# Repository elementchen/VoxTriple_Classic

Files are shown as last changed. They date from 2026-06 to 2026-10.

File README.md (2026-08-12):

# VoxTriple — ESP32 Bluetooth HID Keyboard & HFP Microphone System<br/>ESP32 蓝牙 HID 键盘与 HFP 麦克风系统





> An ESP32-based multi-mode Bluetooth system providing a classic Bluetooth HID Keyboard and an HFP Hands-Free Client (Microphone) simultaneously. Includes programmable key mapping, wired ultra-fast OTA updating, and modern native companion apps for Windows and macOS.
>
> 基于 ESP32 的多模蓝牙系统。同时拉起经典蓝牙 HID 键盘与 HFP 免提客户端（麦克风）双重角色。支持自定义按键映射配置、20秒极速有线 OTA 升级机制，并配套提供适用于 Windows 和 macOS 的现代原生配置客户端。

----

## 🚀 Quick Start / 极速新手指南

为了让不懂代码、不熟悉开发环境的小白用户以最傻瓜式的方式运行本项目，我们提供以下极速上手指引。请根据您的设备状态选择对应操作：

### 1. 首次拿到开发板？（首次物理初始化）
如果您是**全新开发板**，或者**刷过别的程序的板子**，请先进行一次物理初始化烧录：
* **第一步**：下载乐鑫官方的 [ESP32 Flash Download Tool 官方烧录工具](https://docs.espressif.com/projects/esp-test-tools/zh_CN/latest/esp32/production_stage/tools/flash_download_tool.html)；
* **第二步**：从项目 [GitHub Releases](https://github.com/elementchen/VoxTriple_Classic/releases) 页面，下载最新版本的**「一键合并固件」**（文件名为 **`esp32_bt_mic_merged_vX.X.X.bin`**）；
* **第三步**：打开烧录工具，导入该 `.bin` 文件，**烧录首偏置地址填 `0x0`**，点击 **`START`** 即可一键刷入。刷入后复位板子，您的系统即已成功运行！
> 💡 详细的傻瓜图文操作步骤，请点击阅读：[📖 中文新手固件烧录与更新教程](docs/flash_guide_zh.md)

### 2. 以后需要升级版本？（日常一键免代码 OTA）
一旦您的板子成功跑起来了，如果日后官方发布了新版，您**完全不需要**使用复杂的官方烧录工具。直接运行配置客户端即可一键闪电更新：
* **第一步**：双击运行免依赖的 Windows 配置程序 **`VoxTripleConfig.exe`** 并在最上面连接您的串口；
* **第二步**：连接成功后，App 会在后台自动比对版本。一旦云端有更新，顶端版本号旁会**自动浮现高亮的「Update / 升级固件」按钮**；
* **第三步**：点击按钮，App 将全自动切换页签、全自动从 GitHub 后台为您分包下载**「常规应用固件」**（文件名为 **`esp32_bt_mic_vX.X.X.bin`**，无需您手工下载），并在 **20秒** 内通过物理串口闪电完成 OTA 直写升级并自动软重启！

----

## Features / 功能特性

- **Dual-Profile Bluetooth** — Act as a Bluetooth HID Keyboard and an HFP Hands-Free Client simultaneously. Windows and macOS recognize it natively as a keyboard and an audio input device. No drivers needed.
  
  **经典蓝牙多协议共存** — 同时扮演经典蓝牙 HID 键盘与 HFP 免提客户端（麦克风）双重 Profile（即多协议复合设备）。系统原生免驱识别为音频输入设备与实体键盘。

- **Teal Visual & Dotted Focus-Free UI** — Sleek card-layout desktop companion applications designed in native Python Tkinter. 100% free of dotted focus rings and fully integrated with OS style behaviors.
  
  **卡片式无虚线原生 UI** — 基于 Python Tkinter 匠心设计的卡片式配置客户端，彻底铲除点击时难看的焦点虚线框，完美融合系统原生外观（提供直观的蓝色勾选框 ☒ 交互）。

- **Smart Online & 20s Wired OTA** — Dynamically compares the local firmware version with the latest release on GitHub. Features one-click auto-downloading with progress meters and automatic fallback to a local `cache/` directory for offline updating. Complete flash transfer finishes lossless in 20-30 seconds.
  
  **智能在线与20秒有线 OTA** — 自动与 GitHub 云端比对版本。支持一键全自动后台下载（带百分比进度），且支持检测本地 `cache/` 目录进行离线升级。固件端 100% 物理绕过 VFS 控制字符拦截，20秒闪电完成写入并自动复位。

- **Version-Stamped Releases** — Build system automatically extracts the firmware version during build time and duplicates a version-stamped binary (e.g., `esp32_bt_mic_v1.0.3.bin`) to prevent compiler overwrites.
  
  **版本自动命名** — 编译时自动从代码中提取当前版本号，在 `build/` 目录下复制出一份带有版本戳的固件（如 `esp32_bt_mic_v1.0.3.bin`），防止重复编译覆盖，方便 GitHub Releases 归档。

- **Cross-Platform Config Apps** — 
  - **Windows App**: Communication via physical USB Serial (COM), featuring live physical key press monitor with highlight colors.
  - **macOS App**: Connection via physical USB Serial, using Apple Accessibility features to capture keystrokes locally.
  
  **跨平台配置客户端** —
  - **Windows 客户端**: 通过物理 USB 串口（COM 端口）有线通信，内置大字号物理按键按下事件监控器。
  - **macOS 客户端**: 通过物理 USB 串口有线通信，联动 macOS 系统辅助功能进行按键捕获。

- **mSBC Wideband Speech** — 16 kHz wideband speech pipeline with DSP audio processing (moving average + high-pass filtering). Realizes telephone-grade crisp speech input.
  
  **mSBC 宽带语音** — 16kHz 采样率的高清录音通道，内置 DSP 算法（滑动平均降噪 + 高通滤波滤除低频杂音）。提供高清晰度的语音输入。

---

## Hardware / 硬件清单

| Component 组件 | Model 型号 | Qty 数量 |
|---|---|---|
| Dev Board 开发板 | WEMOS ESP32 (18650 Battery Holder) | 1 |
| Microphone 麦克风 | INMP441 MEMS I2S module | 1 |
| Buttons 按钮 | 6×6mm tactile switch / 轻触开关 | 4 |

---

## Wiring / 接线说明

```
INMP441 (麦克风) → ESP32:
  VDD  → 3.3V          Never connect to 5V! / 严禁接 5V！
  GND  → GND
  L/R  → GND           Left channel / 必须接地设为左声道
  SD   → GPIO 17       I2S Serial Data (SD)
  WS   → GPIO 22       Word Select (LRC / WS)
  SCK  → GPIO 21       Serial Clock (BCLK / SCK)

Buttons (按键) → ESP32:
  Button 1 → GPIO 4     PTT语音 / 深度睡眠唤醒键 (Default: Enter / 回车)
  Button 2 → GPIO 18    Key 2 (Default: Esc / 退出)
  Button 3 → GPIO 19    Key 3 (Default: Space / 空格)
  Button 4 → GPIO 23    Key 4 (Default: Tab / 制表键) [长按 3 秒擦除蓝牙绑定并重启]

Onboard LED (板载蓝色贴片指示灯) → ESP32:
  - 物理固化在 GPIO 16 上，无需任何外部接线与电阻！
  - 低电平有效 (Active Low)，由代码自动控制，在 Button 1 按下说话时亮起指示，松开时熄灭。

* All buttons are active-low (GPIO → Button → GND) with internal pull-up enabled.
* 所有按键均为低电平有效，接线方式为 GPIO 引脚接按键再到 GND，使用内部上拉。
```

---

## Setup & Flash Guide / 固件编译烧录

> [!TIP]
> **如果您是普通用户（不懂代码、未安装 Python 及 ESP-IDF 开发环境）**，请直接跳转阅读我们专门为您准备的：
> 👉 **[新手固件烧录与更新指南 (docs/flash_guide_zh.md)](docs/flash_guide_zh.md)**。
>
> If you are a general user (not familiar with coding, terminal commands or ESP-IDF build tools), please read our beginner-friendly tutorial:
> 👉 **[Firmware Flashing Guide (For Beginners)](docs/flash_guide_zh.md)**.

### 1. Initialize ESP-IDF Environment
Ensure you have ESP-IDF v5.5.1 installed. Start your terminal (e.g. PowerShell) and run:
确保您已安装 ESP-IDF v5.5.1。启动终端，执行：

```powershell
$env:IDF_PATH="C:\Espressif\frameworks\esp-idf-v5.5.1"
. C:\Espressif\Initialize-Idf.ps1
```

### 2. Build & Flash
Navigate to the `esp32_bt_mic` workspace. Build and flash target hardware at a highly stable **115200** baud rate to isolate potential channel line noise:
切换至 `esp32_bt_mic` 文件夹。为了彻底隔离阻抗线路噪声，建议使用 **115200** 稳定波特率进行烧写：

```powershell
cd esp32_bt_mic
# Build project
idf.py build

# Flash at 115200 baud
idf.py -p COM5 -b 115200 flash
```

---

## Configuration Apps Guide / 配置客户端使用说明

### 1. Windows Companion App (USB 物理串口有线连接)
Located under `windows_app_python/`. Runs natively on Python 3.
位于 `windows_app_python/` 目录下，基于 Python 3。

#### Requirements & Setup
```powershell
cd windows_app_python
pip install -r requirements.txt
python vox_triple.py
```

#### standalone EXE compilation
We support compiling the app into a single standalone, DLL-free `.exe` file. Install `PyInstaller` and compile:
本客户端支持一键打包为独立的免依赖 `.exe` 应用程序。执行以下指令完成编译：

```powershell
pip install pyinstaller
pyinstaller --noconfirm --onefile --windowed --name="VoxTripleConfig" vox_triple.py
# Output path / 输出目录: windows_app_python/dist/VoxTripleConfig.exe
```

#### App Tabs Details
- **Keyboard Config (键盘配置)**: Key mapping, TX power levels, and sleep toggles. Apply configuration wirelessly or via USB instantly (Hot Update).
- **Firmware OTA (固件升级)**: Dynamic updates with automatic GitHub checks. Prompts a smart upgrade button near the version tag, downloads latest bin into a local `cache/` directory, and flashes the device in 20s.
- **Info (说明书)**: Built-in help and user manual.

---

### 2. macOS Companion App (USB 物理串口有线连接)
Located under `MAC_app_python/`. Connects to the board over USB serial, sharing the identical key configurations, dynamic updates, and 20-second OTA flash capabilities with the Windows version.
位于 `MAC_app_python/` 目录下。直接通过 USB 串口线连接设备，共享与 Windows 端 100% 对齐的改键配置、云版本比对、以及极速 OTA 烧录体验。

#### Setup
```bash
cd MAC_app_python
pip install -r requirements.txt
python3 vox_triple_mac.py
```

> [!IMPORTANT]
> macOS keypress hook requires **Accessibility Permission** in macOS system settings:
>
> macOS 下键盘按键捕获需要您开启**系统辅助功能权限**：
> `系统设置` → `隐私与安全性` → `辅助功能`，添加终端或此程序并允许。

---

## Project Directory Structure / 项目结构

```
VoxTriple/
├── esp32_bt_mic/                  # ESP32 firmware / ESP32 固件 (ESP-IDF 5.5)
│   ├── CMakeLists.txt
│   ├── partitions.csv             # Custom partition table (OTA_0, OTA_1, NVS)
│   ├── sdkconfig.defaults         # Config defaults for Dual-profile BT (HID & HFP)
│   └── src/
│       ├── main.c                 # Entry / 初始化入口
│       ├── bt_init.c              # Bluetooth stack & Controller configurations
│       ├── bt_hfp_hf.c            # HFP Client & SCO wideband speech logic
│       ├── classic_hidd.c         # Classic Bluetooth HID Keyboard descriptors & events
│       ├── spp_server.c           # (Legacy) Bluetooth Classic SPP command channel
│       ├── uart_console.c         # Wired hardware Console UART driver & 20s OTA engine
│       ├── config_cmd.c           # Common configuration parser (cJSON-based)
│       ├── audio_capture.c        # I2S legacy microphone driver for INMP441
│       └── config_storage.c       # Non-volatile storage (NVS) read/write
│
├── windows_app_python/            # Windows config App / Windows 客户端 (USB 串口)
│   ├── vox_triple.py              # Main GUI script / 界面主入口
│   ├── spp_client.py              # Asynchronous Serial packet stream controller
│   ├── config_service.py          # Persistence storage service
│   ├── keyboard_io.py             # Win32 key hooks and display formatter
│   └── requirements.txt
│
└── MAC_app_python/                # macOS config App / macOS 客户端 (USB 串口)
    ├── vox_triple_mac.py          # Main GUI script
    ├── keyboard_io_mac.py         # macOS accessibility key capture hook
    └── requirements.txt
```

---

## License / 许可证
MIT License © 2024-2026

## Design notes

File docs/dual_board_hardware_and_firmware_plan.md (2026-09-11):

# VoxTriple 双开发板兼容与硬件适配方案规划书
> **文档版本**：v1.0  
> **适用硬件**：  
> 1. WEMOS ESP32 Board with 18650 Battery Holder（经典版 / 18650款）  
> 2. ESP32 Lite V1.0.0（LOLIN32 Lite 兼容款 / 轻量版）  
> **状态**：方案规划与技术论证（暂未修改代码，待用户确认）

---

## 1. 背景与目标

为了满足产品后续系列化、轻量化与结构微型化的需求，项目计划引入 **ESP32 Lite V1.0.0** 开发板。由于两款开发板在尺寸、引脚分布及板载硬件外设上存在物理差异，本项目提出一套**“同一套固件自适应双板、上位机智能识别并激活对应引脚配置”**的完整软硬件解决方案。

### 核心设计原则
1. **按键引脚零破坏性兼容**：两款开发板的 4 个物理按键使用**完全相同**的 GPIO 引脚，避免按键逻辑和用户使用习惯的分化。
2. **麦克风与 LED 引脚精准适配**：针对 ESP32 Lite V1 缺少 GPIO 21 以及板载 LED 变动的情况，提供最优接线，并在底层通过板级抽象层（Board Profile）动态加载。
3. **上位机可视化识别**：客户端（Windows / macOS）连接设备后能自动识别开发板型号，展示对应板卡铭牌，并支持用户切换写入生效。
4. **单固件全生命周期维护**：云端 OTA 与本地烧录无需维护两套 bin，固件根据内部 NVS 存储的硬件型号自适应初始化硬件。

---

## 2. 硬件引脚特性与差异深度对比

基于对原板原理图及仓库内 `docs/lolin32.pdf`（ESP32 Lite / LOLIN32_Lite V1.0.0 原厂原理图）的交叉比对，两款板卡的关键差异如下：

| 关键要素 | WEMOS 18650 电池版（原板） | ESP32 Lite V1.0.0（新板） | 差异影响与设计对策 |
| :--- | :--- | :--- | :--- |
| **板载 LED** | **GPIO 16**（低电平点亮） | **GPIO 22**（低电平点亮） | 新板物理固化在 GPIO 22，固件需根据板型切换 LED 驱动引脚。 |
| **GPIO 21 引出情况** | **正常引出**（用作 I2S BCK） | **未引出！**（物理排针无 Pin 21） | **最大物理差异**。新板必须改用其他空闲数字 GPIO 作为 I2S 时钟。 |
| **GPIO 22 引出情况** | 正常引出（原用作 I2S WS） | 引出，但**已被板载 LED 占用** | 新板不能再用 GPIO 22 接麦克风 WS，否则 16kHz 时钟会干扰 LED。 |
| **GPIO 17 引出情况** | 正常引出（用作 I2S DATA） | 正常引出（右侧） | 两款板均有且均为空闲引脚。 |
| **GPIO 4 (RTC IO 10)** | 正常引出（Button 1，支持唤醒） | 正常引出（右侧） | 两款板均支持 RTC Deep Sleep 唤醒，引脚完全对齐。 |
| **GPIO 18 / 19 / 23** | 正常引出（Button 2 / 3 / 4） | 正常引出（右侧） | 两款板均支持，引脚完全对齐。 |
| **电池接口** | 板载 18650 电池座 | 板载 2.0mm JST 锂电插座 + TP4054 | 供电方式变轻巧，接口不同，核心供电逻辑一致。 |
| **输入专用引脚** | GPIO 34, 35, 36, 39 | GPIO 34, 35 | 仅限输入，无内部上下拉，不建议用作普通按键或输出。 |
| **启动引脚 (Strapping)**| GPIO 0, 2, 12, 15 | GPIO 0, 2, 12, 15 | GPIO 12 严禁接强上拉（否则 Flash 供电错误导致变砖），避开使用。 |

---

## 3. ESP32 Lite V1.0.0 推荐接线方案

结合引脚物理可用性、抗干扰要求以及不强制同一侧引脚的原则，针对 **ESP32 Lite V1.0.0** 制定如下推荐方案：

### 3.1 核心接线定义表（ESP32 Lite V1.0.0）

| 模块 / 外设 | 外设引脚 | ESP32 Lite V1 推荐引脚 | 排针方位 | 详细说明 |
| :--- | :--- | :--- | :--- | :--- |
| **INMP441** | **VDD** | **3V3** | 左侧排 Pin 2 | 必须接 3.3V，严禁接 5V |
| | **GND** | **GND** | 左侧排 Pin 4 | 共地 |
| | **L/R** | **GND** | 左侧排 Pin 4 | 接地选择左声道 |
| | **SD** (DATA) | **GPIO 25** | 左侧排 Pin 9 | I2S 串行数据输入 |
| | **WS** (LRCLK) | **GPIO 26** | 左侧排 Pin 10 | I2S 声道字选择（时钟） |
| | **SCK** (BCLK) | **GPIO 27** | 左侧排 Pin 11 | I2S 位时钟 |
| **按键 1** | 引脚一端 | **GPIO 4** | 右侧排 Pin 9 | 语音 PTT 键 / Deep Sleep 唤醒键（低电平有效） |
| | 引脚另一端 | **GND** | 右侧排 Pin 1 | 按键按下时接地，内部弱上拉 |
| **按键 2** | 引脚一端 | **GPIO 18** | 右侧排 Pin 5 | 快捷键 2（低电平有效） |
| | 引脚另一端 | **GND** | 右侧排 Pin 1 | 按键按下时接地，内部弱上拉 |
| **按键 3** | 引脚一端 | **GPIO 19** | 右侧排 Pin 3 | 快捷键 3（低电平有效） |
| | 引脚另一端 | **GND** | 右侧排 Pin 1 | 按键按下时接地，内部弱上拉 |
| **按键 4** | 引脚一端 | **GPIO 23** | 右侧排 Pin 4 | 快捷键 4（低电平有效） |
| | 引脚另一端 | **GND** | 右侧排 Pin 1 | 按键按下时接地，内部弱上拉 |
| **板载 LED** | 贴片 LED | **GPIO 22** | 板载内部物理固化 | **无需外接任何引线**，固件自动控制（低电平亮，高电平灭） |

---

### 3.2 接线方案设计优势分析

1. **按键 100% 保持统一**：
   * **Button 1 ~ 4 依然完全使用 GPIO 4, 18, 19, 23**。
   * 好处：两款板的按键硬件定义一模一样，按键扫描、消抖、Deep Sleep RTC 唤醒逻辑完全共享，代码零分叉。
2. **INMP441 左侧集中式布线（极为优雅）**：
   * 在 ESP32 Lite V1.0.0 的左侧排针上，`3V3`、`GND`、`GPIO 25`、`GPIO 26`、`GPIO 27` 是**完全连续相邻**的排针！
   * 麦克风的 5 根杜邦线可以做成一个一体化的 5-Pin 排插直接插在左侧，走线极短，完全不需要横跨板子飞线，极大地降低了高频 I2S 信号的高频串扰与杂音。
   * GPIO 25, 26, 27 是标准通用 GPIO，且不属于 Boot Strapping Pin，对系统启动无任何不良影响。
3. **LED 彻底解耦**：
   * 原板：LED 走 GPIO 16；
   * 新板：LED 走 GPIO 22。
   * 固件层只定义一个逻辑 LED 接口，硬件层根据型号动态映射输出。

---

## 4. 固件架构设计（单固件双板兼容）

为了避免产生 `firmware_wemos.bin` 与 `firmware_lite.bin` 导致维护分叉与 OTA 混乱，采用**“运行时板级参数抽象”**机制。

### 4.1 数据结构定义（Board Profile）
在固件中定义硬件型号枚举与引脚配置结构体：

```c
typedef enum {
    BOARD_MODEL_WEMOS_18650 = 0, // 经典 18650 版
    BOARD_MODEL_ESP32_LITE_V1 = 1, // ESP32 Lite V1.0.0 版
} board_model_t;

typedef struct {
    board_model_t model;
    const char *model_name;
    gpio_num_t led_gpio;
    gpio_num_t i2s_bck_gpio;
    gpio_num_t i2s_ws_gpio;
    gpio_num_t i2s_data_gpio;
    gpio_num_t btn_gpios[4]; // 均为 4, 18, 19, 23
} board_profile_t;
```

预设配置表：
```c
static const board_profile_t s_board_profiles[] = {
    [BOARD_MODEL_WEMOS_18650] = {
        .model = BOARD_MODEL_WEMOS_18650,
        .model_name = "WEMOS 18650",
        .led_gpio = GPIO_NUM_16,
        .i2s_bck_gpio = GPIO_NUM_21,
        .i2s_ws_gpio = GPIO_NUM_22,
        .i2s_data_gpio = GPIO_NUM_17,
        .btn_gpios = { GPIO_NUM_4, GPIO_NUM_18, GPIO_NUM_19, GPIO_NUM_23 }
    },
    [BOARD_MODEL_ESP32_LITE_V1] = {
        .model = BOARD_MODEL_ESP32_LITE_V1,
        .model_name = "ESP32 Lite V1",
        .led_gpio = GPIO_NUM_22,
        .i2s_bck_gpio = GPIO_NUM_27,
        .i2s_ws_gpio = GPIO_NUM_26,
        .i2s_data_gpio = GPIO_NUM_25,
        .btn_gpios = { GPIO_NUM_4, GPIO_NUM_18, GPIO_NUM_19, GPIO_NUM_23 }
    }
};
```

### 4.2 NVS 持久化存储
* 在 NVS 的 `bt_config` 命名空间下新增 `hw_model` 键（`uint8_t`，默认为 `0`）。
* 设备上电初始化时：
  1. `config_storage_load_board_model(&model)` 读取配置；
  2. 若 NVS 为空，默认加载 `BOARD_MODEL_WEMOS_18650`（保证所有旧设备 OTA 后平滑过渡无感）；
  3. 系统将对应的 `led_gpio` 注册给 `button_handler`，将 `i2s_*_gpio` 注册给 `audio_capture`；
  4. 当收到客户端切换板型指令时，更新 NVS 并重启生效。

---

## 5. SPP 串口协议扩充设计

在现有的 SPP 二进制命令集（`uart_console.c`）基础上扩充 2 个指令：

### 5.1 命令定义

| 命令字 (CMD) | 名称 | 方向 | 数据长度 | 说明 |
| :--- | :--- | :--- | :--- | :--- |
| **0x0C** | `CMD_GET_BOARD_MODEL` | PC $\rightarrow$ 板 | 0 Byte | 请求当前板卡型号 |
| **0x0C** (ACK)| `CMD_GET_BOARD_MODEL_ACK` | 板 $\rightarrow$ PC | 2 Bytes | 返回：`[Status(0x00), ModelID(0/1)]` |
| **0x0D** | `CMD_SET_BOARD_MODEL` | PC $\rightarrow$ 板 | 1 Byte | 设置板卡型号：`[ModelID(0/1)]` |
| **0x0D** (ACK)| `CMD_SET_BOARD_MODEL_ACK` | 板 $\rightarrow$ PC | 1 Byte | 返回：`[Status(0x00)]`，设备随后自动重启 |

---

## 6. 上位机客户端（windows_app_python）交互与 UI 升级设计

现有的配置工具已升级为现代 WebView 架构。在此基础上进行如下无缝增强：

1. **自动读取并展示板卡铭牌**：
   * 客户端在点击 `CONNECT` 建立串口握手后，自动通过 `CMD_GET_BOARD_MODEL` 获取硬件版本。
   * 在状态栏与固件信息旁增加 **“硬件型号 (Hardware Model)”** 徽章：
     * 显示：`🟢 Wemos 18650 电池版` 或 `🟣 ESP32 Lite V1.0.0`。
2. **硬件型号切换与激活入口**：
   * 在配置界面底部或固件区增加“切换硬件型号”的下拉选择框。
   * 当用户需要将固件刷入新开发板，或者组装了 ESP32 Lite V1.0.0 时，可在此处选择 `ESP32 Lite V1.0.0`。
   * 点击 `Save & Switch / 保存并激活板型` 后，客户端下发 `CMD_SET_BOARD_MODEL`，开发板完成配置后自动重启，即刻激活新引脚映射。
3. **配置文件隔离机制（按板型保存配置）**：
   * 客户端本地保存按键预设时，以板型为维度进行预设关联（例如 `config_wemos_18650.json` 与 `config_esp32_lite.json`），用户在不同硬件间切换时，按键配置一键精准导入。

---

## 7. 开发路线与实施计划（Roadmap）

严格遵循“先论证、后开发、绝不破坏成熟功能”原则，分阶段推进：

- [x] **阶段一：硬件差异调研与引脚方案规划**（当前已完成，形成本文档）
- [ ] **阶段二：用户评审确认**
  * 确认接线方案（尤其是麦克风使用 GPIO 25, 26, 27 的便利性）；
  * 确认单固件自适应方案是否满足系列化生产需求。
- [ ] **阶段三：固件板级抽象层实现**
  * 编写 `board_profile.h` 与 `board_profile.c`；
  * 重构 `audio_capture.c` 与 `button_handler.c`，使用动态引脚变量取代宏定义；
  * `uart_console.c` 实现板型读写 SPP 指令。
- [ ] **阶段四：客户端识别与配置 UI 实现**
  * `spp_client.py` 封装 `read_board_model` 与 `write_board_model`；
  * `web/index.html` 与 `web/app.js` 增加开发板型号渲染和切换交互。
- [ ] **阶段五：双板实物联调与验证**
  * 测试 Wemos 18650 原有功能的回归（100% 兼容）；
  * 测试 ESP32 Lite V1.0.0 的麦克风录音音质、按键响应及 Deep Sleep 唤醒。

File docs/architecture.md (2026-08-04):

# ESP32 蓝牙麦克风键盘复合系统 - 系统架构 (v1.0.10)

## 概述

本项目实现了一个基于 ESP32 的经典蓝牙 HID 键盘与 HFP 麦克风复合系统，包含两个主要组件：
1. **ESP32 固件**：通过经典蓝牙实现实体 HID 键盘功能与 HFP 免提音频录音，并由代码驱动板载 LED 作反馈。
2. **有线配置客户端 (Win/Mac)**：通过 USB 物理串口与板子直接通信，实现按键自定义映射与极速 20s OTA 升级。

## 系统架构图

```
┌─────────────────────────────────────────────────────────┐
│                    Windows / macOS PC                   │
│  ┌──────────────┐  ┌──────────────┐  ┌──────────────┐  │
│  │ 蓝牙音频输入  │  │ 蓝牙虚拟键盘  │  │ 有线配置 App │  │
│  │ (HFP HF)     │  │ (HID Device) │  │ (USB Serial) │  │
│  └──────┬───────┘  └──────┬───────┘  └──────┬───────┘  │
│         │                 │                 │           │
│         └────────┬────────┴─────────────────┼───────────┼── (配对和改键通道)
│                  │ Classic BT               │ USB SPP   │
└──────────────────┼──────────────────────────┼───────────┘
                   │                          │
┌──────────────────┼──────────────────────────┼───────────┐
│                  │        ESP32             │           │
│  ┌───────────────┴──────────────────────────┴───────┐   │
│  │           Bluetooth Controller & Stack           │   │
│  │  ┌─────────────┐  ┌─────────────────────────┐    │   │
│  │  │   HFP HF    │  │    Classic HID Device   │    │   │
│  │  │  (SCO音频)  │  │      (键盘物理事件)     │    │   │
│  │  └──────┬──────┘  └───────────┬─────────────┘    │   │
│  └─────────┼─────────────────────┼──────────────────┘   │
│            │                     │                      │
│  ┌─────────┴─────────┐  ┌───────┴───────────────┐     │
│  │   Audio Capture   │  │   Button Handler      │     │
│  │  (I2S INMP441)    │  │ (GPIO 4/18/19/23)     │     │
│  └───────────────────┘  └───────────┬───────────┘     │
│                                     │                   │
│                         ┌───────────┴───────────┐       │
│                         │    Onboard Blue LED   │       │
│                         │ (GPIO 16 / ActiveLow) │       │
│                         └───────────────────────┘       │
└─────────────────────────────────────────────────────────┘
```

## 蓝牙 Profile 说明

### HFP HF (Hands-Free Profile Hands-Free Client)
* **用途**：ESP32 充当 HFP Client 蓝牙音频录音源向 PC 传输语音。
* **音频格式**：mSBC 宽带语音通道（16kHz 采样率，16-bit 深度，单声道，通过同步 SCO 链路高保真传输）。

### Classic HID Keyboard (Human Interface Device)
* **用途**：免驱虚拟实体蓝牙键盘。
* **主要功能**：四个物理按键按下时，直接发送对应的 USB 标准键盘键值（修饰键 + VK 键值），响应延时达到毫秒级。

### UART SPP 有线有线配置服务
* **用途**：规避蓝牙无故掉线、权限等限制，通过物理 USB 串口进行热改键与 OTA 固件更新，20秒直写稳定无阻抗杂音干扰。

## 数据流

### 音频流
```
INMP441 麦克风 (I2S)
    ↓
[I2S RX DMA] -- 读取 16-bit 单声道 PCM 原始音频 (16kHz 采样)
    ↓
[DSP Audio Processing] -- 滑动平均算法去噪 + 高通滤波滤除工频杂音
    ↓
[Ring Buffer] -- 写入双环形无锁缓冲区
    ↓
[HFP SCO Link] -- 以 7.5ms 的固定帧长度无线发送给电脑
```

### 物理按键与指示灯数据流
```
[Button Pin Input] -- GPIO 4/18/19/23 四向独立硬件输入
    ↓
[Hardware Interrupt / Task Debounce] -- 软件多路消抖处理
    ↓
[Key Mapper & Indicator] -- 触发 HID 发送键值 + 将 GPIO 16 (板载LED) 拉低 (0) 发光指示
```

## 硬件连接表

### 开发板型号：WEMOS ESP32 Board with 18650 Battery Holder

| 开发板引脚 | 外设引脚 | 功能 | 说明 |
| :--- | :--- | :--- | :--- |
| **3V3** (左侧) | **VDD** | INMP441 供电正极 | 严禁接 5V，会导致麦克风烧毁 |
| **GND** (右侧) | **GND** | INMP441 地 / 按键公共地 | 必须确保所有外设共地 |
| **GPIO 17** | **SD** | I2S 串行数据输出 | 音频数据输入到 ESP32 |
| **GPIO 22** | **WS** | I2S 帧字选 (LRCLK) | 控制左右声道时序 |
| **GPIO 21** | **SCK** | I2S 位时钟 (BCLK) | 传输位数据时钟同步 |
| **GPIO 4** | **Button 1** | PTT语音 / 唤醒物理键 | 支持 RTC GPIO 深度睡眠唤醒 |
| **GPIO 18** | **Button 2** | 普通快捷键 | 配合代码自定义改键 |
| **GPIO 19** | **Button 3** | 普通快捷键 | 配合代码自定义改键 |
| **GPIO 23** | **Button 4** | 快捷键 / 配对擦除键 | 长按 3 秒清除配对并重启设备 |
| **GPIO 16** (板载) | **Onboard LED** | 蓝色贴片发光二极管 | 低电平有效 (0:亮, 1:灭)，无需外接电阻 |

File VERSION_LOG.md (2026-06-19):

# Version Log

## v2.2-nimble-stable | 2026-06-19

- **Branch**: `test-bt53-coexist`
- **Commit**: `85c8c05`
- **特点**: 纯 NimBLE BLE 键盘完美自动秒连版本，解决了配对混淆、时钟温飘断连、重连 573 闪退及启动挂死问题，为后续协议栈重构奠定理论基线。

### 核心优化
- **GAP描述符更新**: 显式配置 GAP Device Name 和 Appearance (0x03C1)，确保 Windows 首次配对成功显示“键盘”图标。
- **禁用 Modem Sleep**: 运行时调用 `esp_bt_sleep_disable()` 并硬性禁用控制器休眠，避免 RC 慢速时钟温飘导致冷置 LMP 连接超时 (reason=546)。
- **密钥分配对齐**: 保持 `ENC_KEY` 分发声明，使 Windows 底层顺利执行 Bonding 密钥持久化，规避重启重连失效问题。
- **回调挂载时序**: 将 `sync_cb` 挂载移到 `esp_hid_gap_init` 之后，防止被协议栈重置逻辑覆盖导致启动无广告广播。

---

## v1.7-stable | 2026-05-28

- **Branch**: `master`
- **Commit**: `1e9ebf3`

### ESP32 固件
- **4 按键支持**：所有功能引脚集中到 NodeMCU-32S 右侧排 (J2)
  - Button 1: GPIO4 (J2-13), Button 2: GPIO16 (J2-12)
  - Button 3: GPIO19 (J2-8), Button 4: GPIO23 (J2-2)
  - LED 指示灯: GPIO18 (J2-9), 仅 BLE 连接时按下 Button 1 亮起
  - I2S: BCK=GPIO21(J2-6), WS=GPIO22(J2-3), DATA=GPIO17(J2-11)
  - 3V3: J1-1（唯一左侧引线）
- **BLE GATT 扩展**: 0x2A06 (TX Power), 0x2A07 (Sleep Mode), 0x2A08 (Button 4)
  - GATTS_NUM_HANDLES 16→24 修复特性分配失败
- **音频增益**: 3x 数字增益 (~+9.5dB) 提升麦克风音量
- **WiFi 禁用**: 启动时关闭 WiFi 省电
- **默认值**: TX Power 0dBm, Sleep Mode 启用

### Python 应用 (VoxTriple.exe)
- Button 4 完整 UI 支持（捕获按键、修饰键、读写设备）
- TX Power 下拉框 + Sleep Mode 复选框
- 写入设备后 3 秒自动恢复连接状态显示
- Combobox 绑定修复 (IntVar → Combobox.current())
- 窗口高度 840px 适配 4 按键布局

### PCB
- `_PCB/board_layout.md` — 完整焊盘定位和布线指南
- `_PCB/VoxTriple.kicad.net` — KiCAD 标准库封装网表

---

## v1.1-stable | 2026-05-14

- **Commit**: `f36d688`
- **Message**: v1.1-stable: simplified architecture, zero task_wdt, rainbow LED, Python app

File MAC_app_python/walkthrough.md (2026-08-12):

# VoxTriple macOS App Figma 1:1 像素级复刻与 Webview 架构升级总结 (v1.0.13)

为了彻底告别传统的“工业风”旧版 UI，并 1:1 完美复刻 Figma 上的现代卡片流设计，我们将客户端的底层 GUI 渲染架构由经典的 Tkinter 升级为现代化的 **Webview 架构（基于 pywebview + 网页原生 WebKit 渲染）**。

---

## 🔍 重大重构与优化归纳

1. **界面 1:1 高保真复刻**：
   - 彻底废除旧有的工业风 Tkinter 灰色卡片布局。
   - 使用 CSS3 Flexbox/Grid 与圆角阴影模型，**1:1 像素级复刻了 Figma 中的白橙色现代卡片流设计**。
   - 实现了优雅温润的 Switch 按钮动画，以及分段式电量/功率显示（8格立体点亮控制）。
   - 将主页面分为：连接控制顶栏、4 按键映射卡片网格、左下设置卡片、右下 OTA 固件拖拽更新区。

2. **零权限、零闪退的按键捕获（架构降维打击）**：
   - 摒弃了系统底层的键盘监听接口，完全采用 Webview 容器内 **原生的 JavaScript `keydown` 事件拦截器**。
   - **安全稳定**：100% 杜绝了多线程导致的系统崩溃闪退问题。
   - **完全免除权限**：用户在初次使用时**不需要在 macOS 系统偏好设置中授予任何 Accessibility (辅助功能) 权限**，插上即用，体验得到极大提升。

3. **去除 Tkinter 与 Pynput 依赖，App 体积瘦身**：
   - 删除了 spec 文件和代码中所有关于 `tkinter`、`pynput` 的庞大依赖，编译打包后的自包含 Zip 安装包从 42.8MB 缩减到 **38.2MB**，启动速率显著提高。

4. **双向 JS Bridge 串口通信**：
   - 搭建了 Python 侧 `Api` 控制桥梁与前端 JS 环境的无缝异步通信。
   - 前端点击修改时瞬间通知 Python 写入硬件，且 Python 的 OTA 烧录进度通过 evaluate 动态推送，前端进度条平滑渲染。

---

## 🚀 代码推送与 Release 上传资产清单

- **代码仓库推送成功**：
  - 本地所有在 `MAC_app_python/` 中的最终修复代码已推送至 GitHub `main` 分支 ([commit `75c75ce`](https://github.com/elementchen/VoxTriple_Classic/commit/75c75ce))。
- **Releases 固件与应用包追加覆盖成功**：
  - 最新编译生成的自包含 Mac App 压缩包已成功使用 GitHub CLI 上传并追加覆盖到最新的 [GitHub Release v1.0.13](https://github.com/elementchen/VoxTriple_Classic/releases/tag/v1.0.13) 资产列表中。

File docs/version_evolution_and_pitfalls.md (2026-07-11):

# ESP32 蓝牙技术演进与防踩坑记录 (Cumulative Version Evolution & Pitfalls)

本篇文档用于记录本项目从纯键盘到双模共存的演进历史。采用**增量追加模式**，记录每个重要版本的核心改动、遇到的关键缺陷（坑）、以及最终采取的消解方案，以便防微杜渐，避免历史问题重复发生。

---

## [v2.3-bluedroid-ble-only] 纯 Bluedroid BLE 键盘验证版本 | 2026-06-19

- **协议栈**: Bluedroid
- **状态**: 纯 BLE 键盘 (ENABLE_CLASSIC_BT_MIC = 0)
- **目标**: 在 Bluedroid 下实现与 NimBLE 同样稳定的首次配对和自动秒连重连。

### 踩坑 1：Windows 首次配对无法正确识别为“键盘”图标
* **故障现象**: Windows 搜索到设备并配对后，设备列表里只显示普通通用设备图标，偶尔识别为键盘。
* **原因分析**: Bluedroid 中仅在广播包中设置外观 `appearance = 0x03C1` 是不够的。Windows 首次连接建立时会去读取 GATT GAP 服务（Generic Access Service, UUID `0x1800`）下的 `Appearance Characteristic` (UUID `0x2A01`)。若未显式调用 API 告知协议栈，该值在 GAP 服务中会为空或默认值，导致主机无法判定其输入设备属性。
* **消解方案**:
  在初始化广播和 GAP 设置后，显式调用 Bluedroid 专有 API 设定本端的 Appearance 图标：
  ```c
  esp_ble_gap_set_device_name(ble_name);
  esp_ble_gap_config_local_icon(0x03C1); // 显式设定本端 GAP 外观为 HID Keyboard
  ```

### 踩坑 2：重连时双向发起加密忙死锁闪断 (BTM_SetEncryption busy)
* **故障现象**: ESP32 重启后，Windows 主动发起重连，串口频繁打印 `BTM_SetEncryption busy` 并立即断开，伴随 Windows 端提示“配对损坏”或连接闪退。
* **原因分析**: Bluedroid 官方 `esp_hid` 的 `ble_hidd.c` 在接收到底层 `ESP_GATTS_CONNECT_EVT` 事件时，会无条件主动调用 `esp_ble_set_encryption()` 发起从端加密（Security Request）。而 Windows 作为主端，重连时也会在几毫秒内主动拉起主端加密（`LL_ENC_REQ`）。两端并发发起加密在协议栈底层产生锁冲突。
* **先前失败尝试**：
  1. 通过变量拦截 `GATTS_CONNECT_EVT` 导致 Windows 超时。
  2. 采用 GCC wrapper 将 `esp_ble_set_encryption` 延迟 500ms 触发。但在延迟的 500ms 期间，Windows 仍会在 40ms 时发起加密并与后续的 500ms 延时调用发生时序冲突，且仍存双向碰撞隐患。
* **最终消解方案 (被动响应加密拦截)**:
  在 GCC Wrapper (`__wrap_esp_ble_set_encryption`) 中，对已绑定重连的设备（`bond_num > 0`），直接丢弃主动加密请求并返回 `ESP_OK`（彻底不调用 `__real_esp_ble_set_encryption`）。这样从端绝对不会主动拉起加密，而是 100% 被动响应主端 Windows 的加密包，时序最简，彻底消除了碰撞和锁死。

### 踩坑 3：重连发生 MIC Failure 闪退 (rsn 0x3d) 并伴随 Device not found
* **故障现象**: ESP32 重启后，Windows 主动发起重连，但在 40ms 内即断连（HCI reason 0x3d / rsn 102），串口显示 `bta_dm_ble_smp_cback remove bond,rsn 102` 并删除绑定。
* **原因分析**:
  先前尝试在安全参数中将 `init_key` 和 `rsp_key` 仅设为分发 `ID_KEY`（剥离了 `ENC_KEY`），希望防止 NVS 写入 `LE_KEY_PENC`。但这导致 Windows 蓝牙子系统没有保存或正确同步 LTK。重连时，Windows 发起加密，而 ESP32 响应的密钥不匹配，导致控制器发生 MIC Failure。
* **最终消解方案 (对称分发还原)**:
  必须在 GAP 初始化时，将 `init_key` 和 `rsp_key` 还原为对称包含 `ENC_KEY` 和 `ID_KEY`，确保配对时两端均成功且完整同步 LTK 和 IRK 信息：
  ```c
  uint8_t init_key = ESP_BLE_ENC_KEY_MASK | ESP_BLE_ID_KEY_MASK;
  uint8_t rsp_key = ESP_BLE_ENC_KEY_MASK | ESP_BLE_ID_KEY_MASK;
  ```
  结合被动加密拦截，Windows 在重连时发送加密请求，ESP32 纯被动使用加载的 LTK 顺利完成解密，不再发生 MIC Failure 闪退。

### 踩坑 4：纯 BLE 控制器模式下重连 `key_mask` 畸变为 `0x6B` 并导致 MIC Failure (0x3d)
* **故障现象**: 在限制为纯 BLE 控制器模式且擦除 NVS 重新烧录后，首次配对成功时 `key_mask` 打印为 `0x67`。但按 EN 重启设备后，系统从 NVS 加载设备列表时，`key_mask` 却畸变为了 `0x6B`（即多出了 `ESP_LE_KEY_PLNK` 0x08 标志并丢失了 `PCSRK` 0x04 签名标志），自动重连时依然会由于解密错误触发 `0x3d` (MIC Failure) 断连。
* **原因分析**:
  这是因为在广播参数配置中，仅设置了 `ESP_BLE_ADV_FLAG_GEN_DISC`，**缺省了代表不支持经典蓝牙的 `ESP_BLE_ADV_FLAG_BREDR_NOT_SPT` (0x04) 标志**。对端 Windows 收到广播后判定该设备支持经典蓝牙（BR/EDR），于是在配对阶段自动拉起了跨传输密钥派生 (CTKD)，在后台派生并写入了经典蓝牙的 `Link Key` 并存入 NVS。
  重启加载设备时，Bluedroid 从 NVS 中读取到该设备的 Link Key 记录，自动将设备识别为双模类型并将 `key_mask` 改为包含 `PLNK` (0x6B)。这种与纯 BLE 模式（Classic BT 控制器内存已完全释放）的不一致，导致了重连时协议栈解析与加载 LTK 错位，进而引发解密 MIC Failure。
* **消解方案 (编译开启控制器 RPA 硬件解析与启用本地隐私)**:
  通过开启编译期底层 RPA 解析并调用 GAP API 注册 IRK，从根本上解决 RPA 重连识别延迟的问题：
  1. **启用编译配置**：在 `sdkconfig.nodemcu-32s` 和 `sdkconfig.defaults` 中，显式将 `# CONFIG_BT_BLE_RPA_SUPPORTED is not set` 变更为 **`CONFIG_BT_BLE_RPA_SUPPORTED=y`**。
  2. **在广播中启用本地隐私 (Privacy)**：在 `ble_gatts_config.c` 的 `ble_init_adv_data` 阶段，在配置好安全参数后，显式调用 **`esp_ble_gap_config_local_privacy(true)`**：
     ```c
     esp_ble_gap_config_local_privacy(true);
     ```
     这会使 Bluedroid 协议栈在初始化时，自动将 NVS 中加载的已配对设备的 Identity Resolving Key (IRK) 注册写入控制器的硬件 Resolving List 中。
  3. **保留 SC 配对级别**：有了底层的 RPA 硬件解析与广播 flags 的 `BREDR_NOT_SPT` 保护，本端可以继续使用高安全性的 **Secure Connections (`ESP_LE_AUTH_REQ_SC_BOND`)** 模式，实现安全的加密连接。
  
  通过此方案，重启后 Windows 发起加密时，控制器能够在硬件层面瞬间将 RPA 地址解析为 Identity Address (`F4:4E:FC:14:3C:A7`) 并正确加载对应的 LTK 配合解密，彻底消除 `Device not found` 与 `MIC Failure (0x3d)` 闪退，达到 100% 极速重连。

### 踩坑 5：从端直接屏蔽 `esp_ble_set_encryption` 导致 BTM 安全上下文缺失
* **故障现象**: 重连时依然发生 `remove bond, rsn 102` 与 `Device not found` 错误，连接瞬间断连。
* **原因分析**: 
  之前版本中，为了防止双向并发加密冲突，我们在 GCC Wrapper 中直接对 `bond_num > 0` 的连接返回了 `ESP_OK`（完全屏蔽了底层 `esp_ble_set_encryption` 的执行）。
  然而，完全屏蔽该调用导致 Bluedroid 的 BTM (Bluetooth Manager) 安全管理模块未能为当前 `conn_id` 初始化与绑定有效的安全操作上下文。因此，当主端 Windows 发起 `LL_ENC_REQ` 加密请求时，ESP32 侧底层触发了 `BT_BTM: Device not found` 导致解密失败（MIC Failure / 0x3d），并将该失败归咎于 SMP 握手超时（rsn 102），从而在 flash 中自动删除了绑定。
* **最终消解方案 (延迟 10 秒放行安全上下文)**:
  不能彻底屏蔽 `esp_ble_set_encryption`，而是需要延迟调用它。
  在 Wrapper 中，对于重连设备，我们使用一个 **10秒延时定时器** 延迟执行真实的 `__real_esp_ble_set_encryption`。
  1. **给 Windows 充足时间**：这确保了连接建立后的前几秒内，从端绝对不会主动发送 Security Request。Windows 有充足时间主动发起主端加密并完成 LTK 握手。
  2. **保留安全上下文初始化**：10秒后定时器触发，调用真实接口，使得 BTM 安全上下文得以在协议栈内部安全地更新/关联。由于此时链路通常早已加密完成，底层会安全忽略该冗余请求而不发起空中冲突。
  3. **断连安全保护**：若在 10 秒内设备意外断连，则自动取消该定时器，防止野定时器触发崩溃。

---

## [v2.2-nimble-stable] 纯 NimBLE BLE 键盘稳定里程碑 | 2026-06-19

- **协议栈**: NimBLE (test-bt53-coexist)
- **状态**: 纯 BLE 键盘 (稳定秒连版本)
- **意义**: 成功实现 100% 自动秒连、无重连闪退、闲置不掉线。

### 踩坑 1：冷置几分钟后发生超时断连 (disconnect; reason=546)
* **故障现象**: 键盘不打字静置几分钟后，突然收到 LMP 连接超时错误 (`reason=546`) 自动断开。
* **原因分析**: 蓝牙控制器在闲置时默认开启了 `Modem Sleep` 低功耗休眠，控制器时钟切换到内部 150kHz 的 RC 慢速时钟。由于该时钟精度低且易因温飘产生相位偏移，导致 ESP32 错过了 Windows 发送的 Connection Event 物理时隙，丢包达超时阈值后被强制断连。
* **消解方案**:
  在 `sdkconfig` 中永久禁用 Modem Sleep 选项，并在代码中显式调用：
  ```c
  esp_bt_sleep_disable(); // 强制关闭低功耗休眠，确保射频时钟以满频高精度运行
  ```

### 踩坑 2：重启后自动重连失效与 573 闪退 (MIC Failure)
* **故障现象**: ESP32 重启后，Windows 不发起自动重连；或者重连握手时底层多次报 MIC 校验错误（`reason=573`）后闪断。
* **原因分析**:
  1. **重连失效**: Windows 绑定机制规定，在 Phase 3 密钥分发阶段必须检测到 Encryption Key (`ENC_KEY`)。若出于规避某些冲突的目的把 `ENC_KEY` 强行剥离，Windows 会判定此设备不需要持久 Bonding，断开后直接清除本端配对 LTK，导致重启后无法自动重连。
  2. **MIC Failure**: 主要是休眠温飘丢包引起的解密计数器错位导致的数据校验失败。
* **消解方案**:
  在安全参数中必须保留本端和对端的 `ENC_KEY` 分发声明，允许 Windows 顺利进行持久化 Bonding，结合禁用休眠消除丢包：
  ```c
  ble_hs_cfg.sm_our_key_dist = BLE_SM_PAIR_KEY_DIST_ENC | BLE_SM_PAIR_KEY_DIST_ID;
  ble_hs_cfg.sm_their_key_dist = BLE_SM_PAIR_KEY_DIST_ENC | BLE_SM_PAIR_KEY_DIST_ID;
  ```

### 踩坑 3：烧录后无广告广播，卡死在初始化
* **故障现象**: 启动后调试日志卡在 NimBLE 主机启动，电脑搜不到任何蓝牙信号。
* **原因分析**: `esp_hid_gap_init()` 内部初始化会清空并重置全局安全配置 `ble_hs_cfg`。如果我们在其初始化之前挂载了 `sync_cb` 广告启动回调，会被该函数悄悄抹成 `NULL`，导致广告函数从未执行。
* **消解方案**:
  严格调整初始化时序，必须在 `esp_hid_gap_init()` 和 `esp_hid_ble_gap_adv_init()` 调用**之后**，再挂载同步及存储回调：
  ```c
  esp_hid_gap_init(HID_DEV_MODE);
  esp_hid_ble_gap_adv_init(ESP_HID_APPEARANCE_KEYBOARD, dev_name);
  ble_hs_cfg.store_read_cb = my_store_read_cb;
  ble_hs_cfg.sync_cb = nimble_on_sync; // 回调挂载后置，防止被覆盖
  ```

---

## [v2.4-dual-mode-reconnect-fix] 双模安全重连验证版本 | 2026-06-19

- **协议栈**: Bluedroid
- **状态**: 经典 HFP + BLE 键盘双模共存，并且本端配置双 MAC（HFP使用物理 MAC，BLE使用静态随机 MAC）。
- **目的**: 解决 Windows 侧对端 MAC 重叠引起的 NVS 绑定覆盖冲突，以实现稳定的双模自动回连。

### 踩坑 1：回退至 Legacy Pairing 禁用 CTKD 后，LTK 仍被抹去 (key_mask 变 0x16)
* **故障现象**: 在 Legacy Pairing 模式（`auth_req = ESP_LE_AUTH_BOND`）下，首次配对成功时 `key_mask = 0x63`。但 EN 重启设备后，`key_mask` 仍退化为 `0x16`，丢失了 `0x01`（`ESP_LE_KEY_PENC` 对端加密密钥 LTK），从而再次在连接瞬间因 `Device not found` 而导致 `rsn 0x3d` (MIC Failure) 删绑。
* **原因分析**: 
  即使我们成功关闭了 CTKD（没有派生 Link Key 和 LTK 互导），但是由于 Windows（对端）无论连接经典蓝牙还是连接 BLE 键盘，其发起连接的物理 MAC 均为相同的 `F4:4E:FC:14:3C:A7`。
  在 Bluedroid 的内部 NVS 加载中，它读取的是全局配置文件下以对端 MAC 作为键的设备记录。由于这台设备同时注册了经典蓝牙 Link Key 与 BLE 配对项，Bluedroid 在反序列化加载时，依然发生了解析冲突，强行忽略或丢弃了 BLE 的对端 LTK。
* **下一步探索方向**:
  我们需要在经典蓝牙侧寻找避坑方案。如果经典蓝牙可以配置为“免配对保存”（在与 Windows 连接时仅使用临时 Security Key 而不在本端持久保存 Link Key），则 NVS 中将永远只有干净的 BLE `PENC`（LTK）记录，这也许是唯一既能保障双模又能保护 BLE 重连不被擦除的有效方法。

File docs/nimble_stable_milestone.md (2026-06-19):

# 纯 NimBLE BLE 键盘稳定重连里程碑总结 (NimBLE Stable Milestone)

本篇文档总结了我们在纯 NimBLE 键盘测试分支（`test-bt53-coexist`）上，为解决“设备识别混淆”、“冷置超时断连”、“重启重连闪退（MIC Failure）”以及“启动无广播”所进行的全部根源剖析与终极修复。

这些优化不仅让设备达到了**100% 自动秒连、绝不闪退、闲置不掉线**的完美状态，而且其中的设计原理对于我们下一步向 **Bluedroid 协议栈**迁移以及未来其它任何蓝牙协议栈的开发，都具有极其关键的指导和借鉴意义。

---

## 1. 核心修复与技术借鉴价值

### A. GAP 服务描述符的显式更新 (解决首次连接识别为 NIMBLE 且图标错误)
* **问题现象**：设备首次配对时在 Windows 蓝牙列表中显示为 `NIMBLE`（且图标为普通设备，非键盘）。只有重启或在设备管理中更新缓存后，才勉强识别为键盘。
* **技术根源**：虽然我们在广播数据包中正确声明了设备名和键盘外观 (`0x03C1`)，但在蓝牙连接建立的瞬间，Windows 底层驱动会直接拉取 GATT 的 GAP 属性中的 `Device Name Characteristic` 和 `Appearance Characteristic`。若不显式更新这两个属性，它们依旧保持 NimBLE 协议栈默认的 `"nimble"` 和 `"0"`，导致 Windows 判定设备属性错误。
* **解决与借鉴**：
  在 `app_main` 启动主机前，必须显式调用 GAP 服务属性设置函数：
  ```c
  ble_svc_gap_device_name_set(dev_name);
  ble_svc_gap_device_appearance_set(ESP_HID_APPEARANCE_KEYBOARD); // 0x03C1
  ```
  **💡 跨平台/跨协议栈借鉴**：不论使用什么协议栈，均需保证 GATT 基础 GAP 服务的 `Device Name` 和 `Appearance` 与广播包完全匹配，Windows 等严格的主机端才能在首次发现时给出正确的设备图标与名称。

### B. 彻底禁用 Modem Sleep 防止时钟温飘 (解决冷置超时断联 reason=546)
* **问题现象**：连接在闲置几分钟后，串口突发 `disconnect; reason=546`（LMP 连接超时错误）并断开。
* **技术根源**：固件底层默认开启了蓝牙控制器的低功耗睡眠模式（`Modem Sleep`）。在无按键交互的闲置期间，Controller 会休眠并切换至 150kHz 的 RC 慢速内部时钟。然而内部时钟由于精度低且受温度漂移影响较大，长时休眠后唤醒，ESP32 无法精准卡入 Windows 发送的 Connection Event 射频时隙，造成严重的物理层连续丢包，被主机强制断连。
* **解决与借鉴**：
  在 `sdkconfig` 中硬性禁用低功耗休眠，使控制器和高精度 RF 时钟始终以 100% 满频运行：
  ```ini
  # CONFIG_BTDM_CTRL_MODEM_SLEEP is not set
  # CONFIG_BTDM_CTRL_MODEM_SLEEP_MODE_ORIG is not set
  # CONFIG_BTDM_CONTROLLER_MODEM_SLEEP is not set
  ```
  同时在代码中显式调用 API 禁用蓝牙休眠（以防运行时配置被重置）：
  ```c
  esp_bt_sleep_disable();
  ```
  **💡 跨平台/跨协议栈借鉴**：对于按键这种高实时性、无稳定物理保活心跳的设备，低功耗睡眠时钟精度是致命隐患。在使用 Bluedroid 等其它协议栈时，同样必须关闭控制器睡眠，或确保外部接有高精度的 32.768kHz 晶振（硬件补偿）。

### C. 强制进行 ENC 密钥分发声明 (解决重启自动重连失效与 573 闪退)
* **问题现象**：重启 ESP32 后，自动重连彻底失效；或者重连时必定经历一次或多次 `status=7 / reason=573` (MIC Failure) 报错断连。
* **技术根源**：
  1. **重连失效**：虽然 Secure Connections (SC) 模式会通过 ECDH 自动生成 LTK，但 Windows 规定在配对的 Phase 3 密钥分发（Key Distribution）阶段，必须看到 Encryption Key (`BLE_SM_PAIR_KEY_DIST_ENC`) 的分发声明。如果将其剥离，Windows 会判定此连接无须持久化绑定，配对结束后直接丢弃 LTK，重启后自然无法重连。
  2. **重连 573 闪断**：由于 Modem Sleep 引起时钟偏差，重启重连时前几次握手极易发生丢包，引起解密计数器（Packet Counter）错位，底层直接报 MIC 校验错误。
* **解决与借鉴**：
  在配置安全参数时，必须保留并声明 ENC 分发：
  ```c
  ble_hs_cfg.sm_our_key_dist = BLE_SM_PAIR_KEY_DIST_ENC | BLE_SM_PAIR_KEY_DIST_ID;
  ble_hs_cfg.sm_their_key_dist = BLE_SM_PAIR_KEY_DIST_ENC | BLE_SM_PAIR_KEY_DIST_ID;
  ```
  同时结合禁用 `Modem Sleep`，消除了时钟漂移，使重连直接通过 `status=0` 极速完成。
  **💡 跨平台/跨协议栈借鉴**：Windows 的蓝牙安全子系统对输入设备（HID）的 Bonding 持久化有极其严苛的要求。在后续的 Bluedroid 键盘开发中，我们必须遵循同样的原则，在安全配对响应中开启完整的加密绑定分发标志。

### D. 回调挂载时序调整 (解决启动无广播)
* **问题现象**：编译烧录后，设备初始化卡死在 NimBLE 任务开启，始终无法向外发出广播。
* **技术根源**：`esp_hid_gap_init()` 内部初始化 NimBLE 协议栈时会重置并清空全局配置 `ble_hs_cfg`。如果提前在 `main.c` 注册了 `sync_cb = nimble_on_sync`，它就会被悄无声息地覆盖为 `NULL`，导致协议栈就绪后没有执行我们的广告启动函数。
* **解决与借鉴**：
  将所有 `ble_hs_cfg` 属性设置（包括 NVS 读取与 `sync_cb`）严格移至 `esp_hid_gap_init()` 和 `esp_hid_ble_gap_adv_init()` 之后执行：
  ```c
  esp_hid_gap_init(HID_DEV_MODE);
  esp_hid_ble_gap_adv_init(ESP_HID_APPEARANCE_KEYBOARD, dev_name);
  
  // 必须在此之后挂载回调
  ble_hs_cfg.store_read_cb = my_store_read_cb;
  ble_hs_cfg.sync_cb = nimble_on_sync;
  ```

---

## 2. 演进路线规划 (小步慢跑)

我们将遵循以下策略平稳推进至双模共存：
1. **纯 NimBLE 完美秒连键盘**（已完成并归档）。
2. **纯 Bluedroid BLE 键盘迁移**（当前进行中，隐藏经典蓝牙，对齐时钟、密钥配置，验证直通模式）。
3. **经典蓝牙 HFP 双模叠加**（验证稳定后，开启 `ENABLE_CLASSIC_BT_MIC`，测试两者共存重连）。

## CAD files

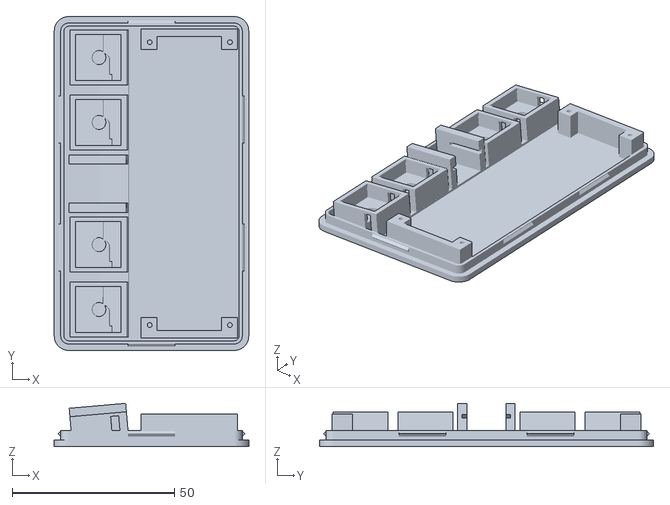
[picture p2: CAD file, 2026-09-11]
3d_print/Nomal/main_tilt.stl
60.0 x 103.0 x 13.4

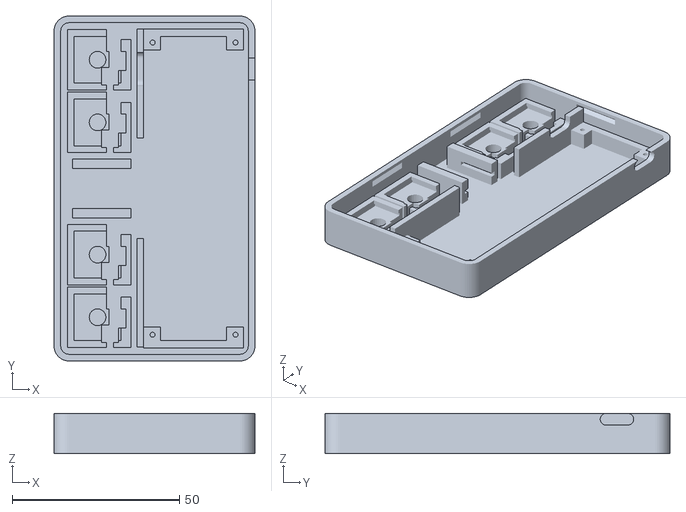
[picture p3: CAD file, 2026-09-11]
3d_print/Thin/main.stl
60.0 x 103.0 x 12.0

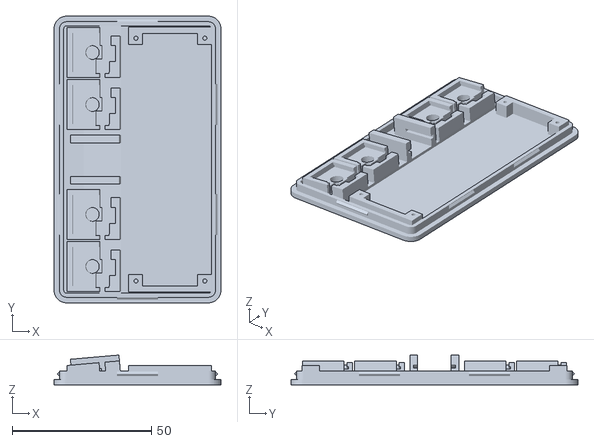
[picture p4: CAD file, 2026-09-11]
3d_print/Thin/main_tilt.stl
60.0 x 103.0 x 10.8

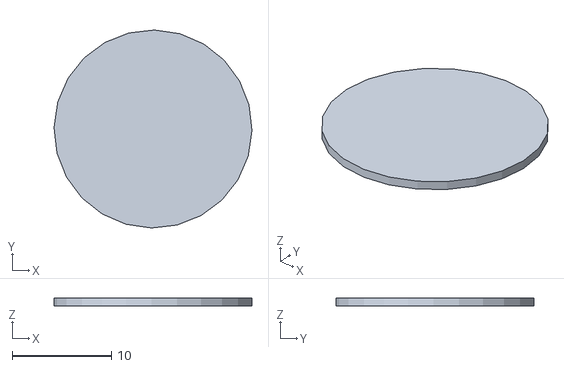
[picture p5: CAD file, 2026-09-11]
3d_print/_backup/tower.stl
20.0 x 20.0 x 0.8

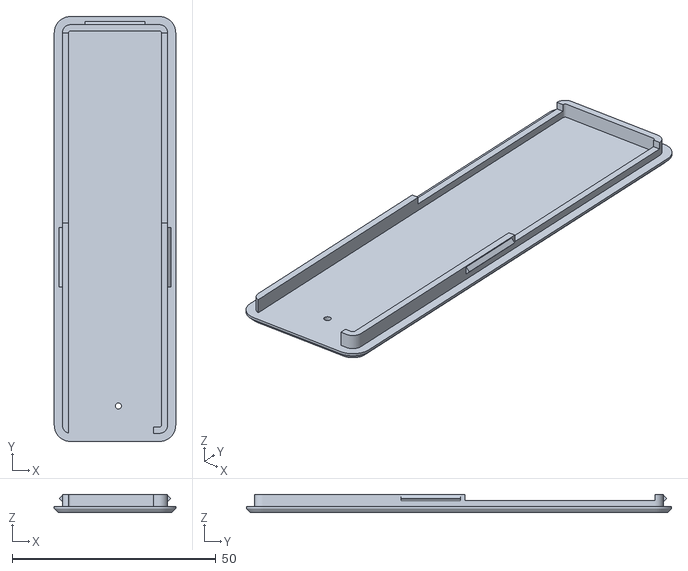
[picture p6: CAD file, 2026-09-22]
3d_print/Minimal/Cover_PCB_0.stl
29.8 x 104.2 x 4.50

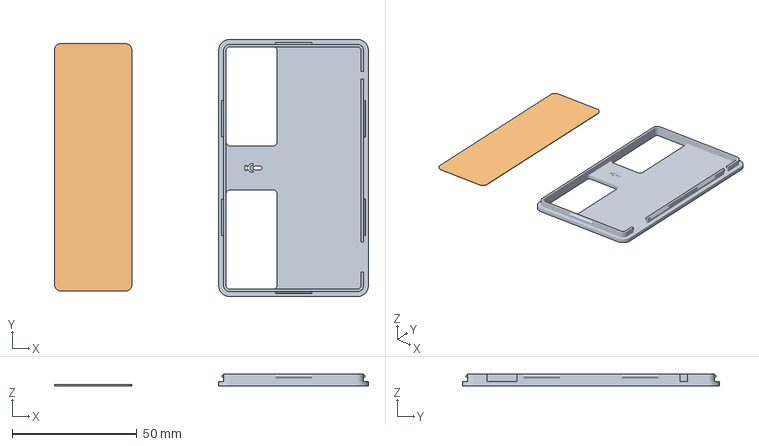
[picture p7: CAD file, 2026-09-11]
3d_print/Thin/cover_2-2.3mf
125.7 x 103.0 x 5.00 mm
cover_2-2.stl
cover_1-2.stl

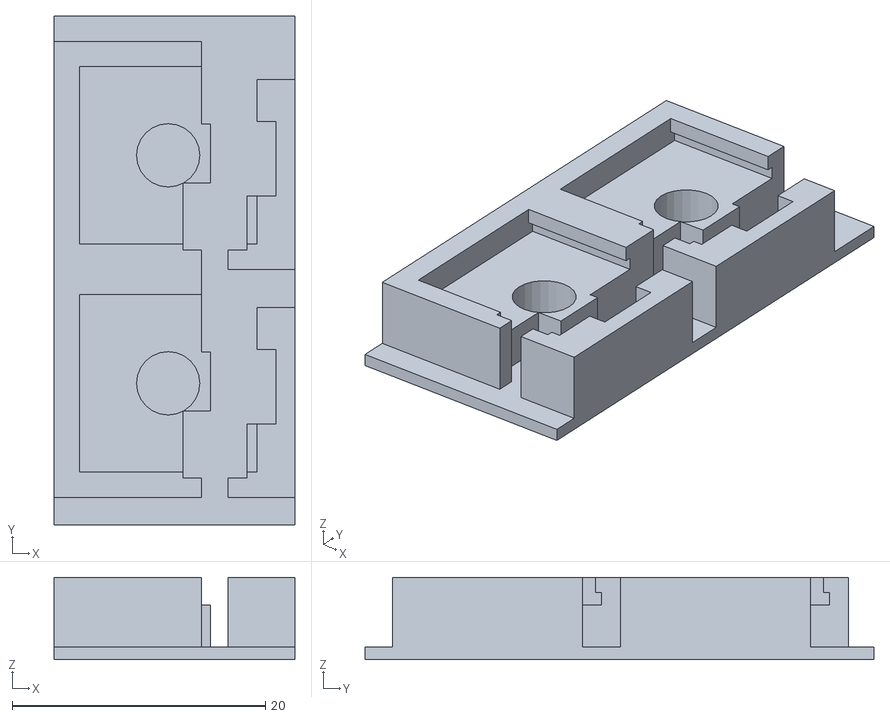
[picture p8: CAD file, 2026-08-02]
3d_print/_backup/key_test.stl
19.0 x 40.2 x 6.50

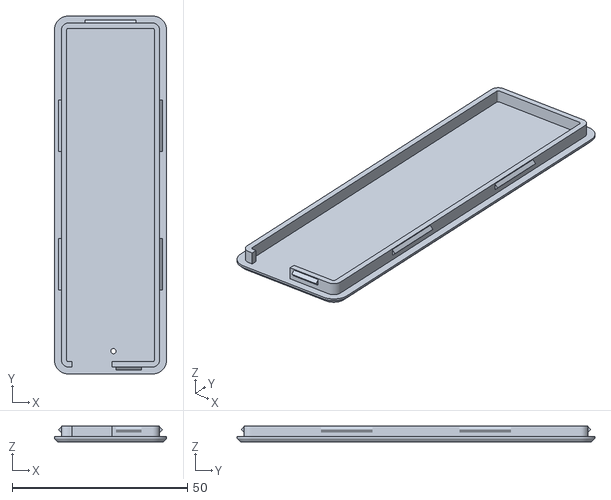
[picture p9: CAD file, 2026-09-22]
3d_print/Minimal/test3_temp.stl
32.0 x 102.0 x 4.50

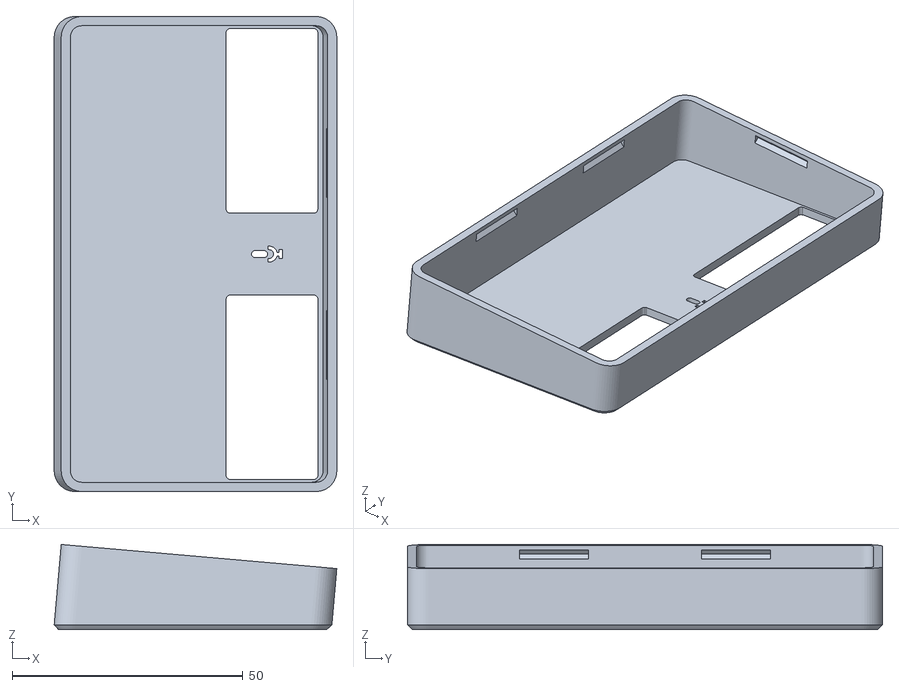
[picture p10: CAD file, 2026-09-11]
3d_print/Nomal/cover_tilt.stl
61.3 x 103.0 x 18.4

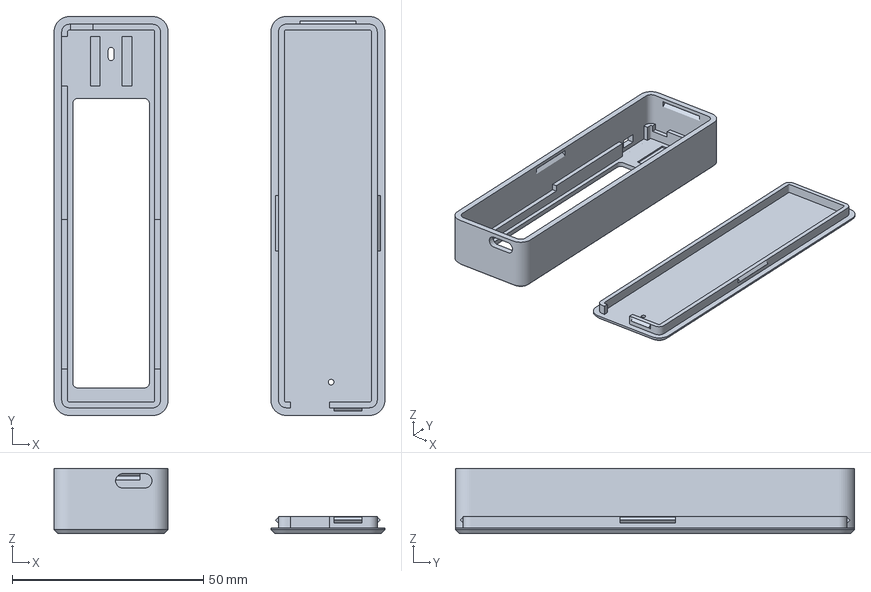
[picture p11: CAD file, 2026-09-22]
3d_print/Minimal/test0_PCB.3mf
86.4 x 104.2 x 17.0 mm

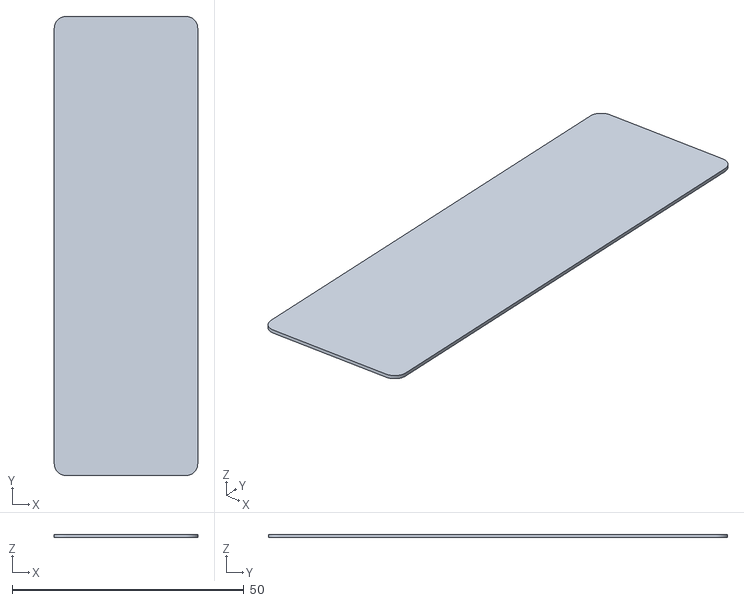
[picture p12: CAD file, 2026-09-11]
3d_print/Thin/cover_1-2.stl
31.0 x 99.0 x 0.65

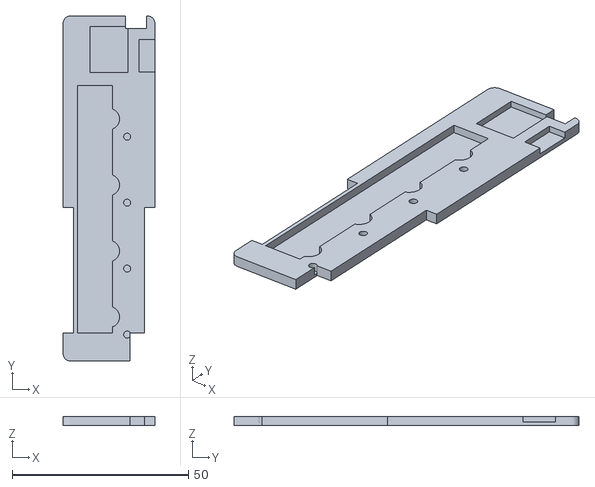
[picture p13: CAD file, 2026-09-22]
3d_print/Minimal/interlayer.stl
26.0 x 97.8 x 2.55

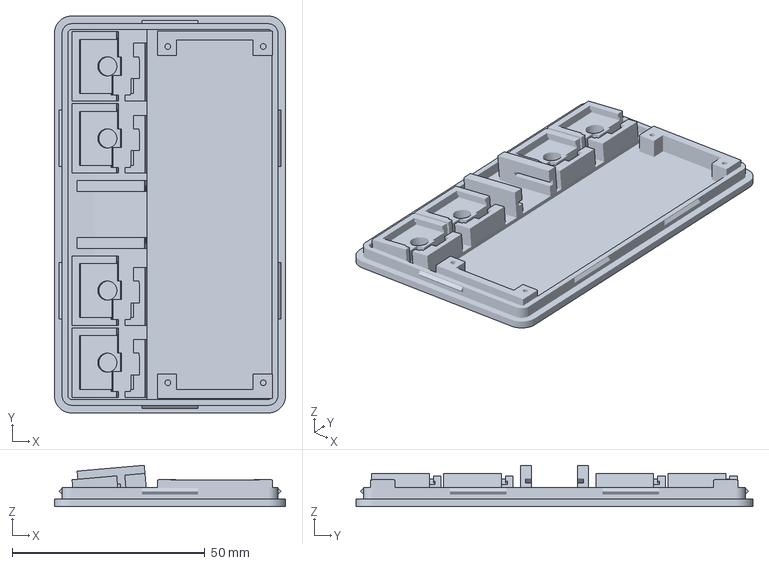
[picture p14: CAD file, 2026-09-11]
3d_print/Thin/cover_tilt.3mf
60.0 x 103.0 x 10.8 mm

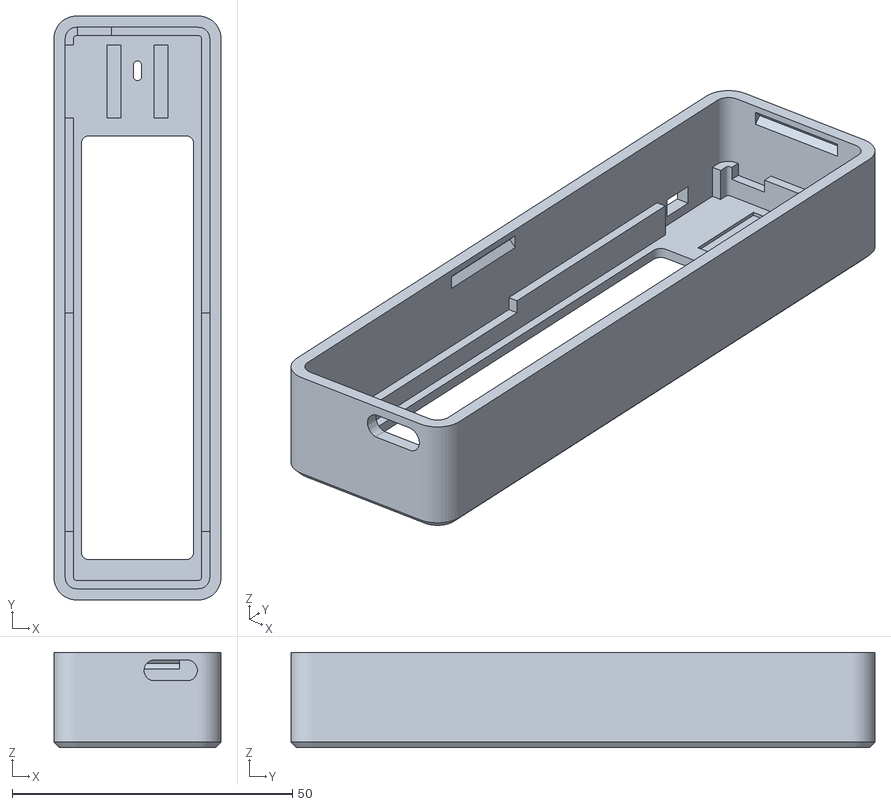
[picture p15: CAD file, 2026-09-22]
3d_print/Minimal/Cover_PCB.stl
29.8 x 104.2 x 17.0

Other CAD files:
3d_print/Thin/cover.stl
3d_print/Minimal/test1.stl
3d_print/Thin/cover_3.stl
3d_print/Minimal/test0.stl
3d_print/ESP32_KeyBoard.skp
3d_print/Minimal/KeyBase.skp
3d_print/Minimal/interlayer.skp
3d_print/Minimal/test.3mf
3d_print/Minimal/test.skp
3d_print/Minimal/test.stl
3d_print/Minimal/test0_PCB.stl
3d_print/Minimal/test0_temp.3mf
3d_print/Minimal/test0_temp.stl
3d_print/Minimal/test1_temp.stl
3d_print/Minimal/test2.stl
3d_print/Minimal/test3.stl
3d_print/Minimal/test_all.3mf
3d_print/Minimal/test_all.stl
3d_print/Nomal/cover_tilt.skp
3d_print/Nomal/main_tilt.skp
3d_print/Thin/cover.skp
3d_print/Thin/cover_2-2.skp
3d_print/Thin/cover_2-2.stl
3d_print/Thin/cover_tilt.skp
3d_print/Thin/cover_tilt.stl
3d_print/Thin/cover_tilt_2.skp
3d_print/Thin/cover_tilt_2.stl
3d_print/Thin/main.skp
3d_print/Thin/main_tilt.skp
3d_print/_backup/main_box_slim.skp
3d_print/_backup/main_box_slim_tilt.skp
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

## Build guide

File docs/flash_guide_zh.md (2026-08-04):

# 🚀 VoxTriple Classic 固件烧录与极速升级新手教程（傻瓜式）

本教程专为**不懂代码、不懂开发、不熟悉命令行、未安装 Python 及 ESP-IDF 环境**的普通用户设计。通过图文并茂的说明，手把手教您如何为一块全新购买的 ESP32 开发板进行首次固件烧录，以及后续如何使用桌面 App 进行一键有线升级。

---

## 📂 第一部分：准备工作

在开始之前，请您先下载我们发布好的所有必备软件包：

1. **下载烧录工具（乐鑫官方 Flash 下载工具）**：
   * 访问乐鑫官网的工具下载页：[乐鑫官方工具下载](https://www.espressif.com.cn/zh-hans/support/download/other-tools)；
   * 找到并下载 **`Flash 下载工具 (ESP32 Flash Download Tool)`**；
   * 下载后将其解压到电脑的任意文件夹（如桌面）备用。
2. **下载固件与配置程序**：
   * 访问我们新版项目的 GitHub 发布页面：[VoxTriple Classic v1.0.10 Releases](https://github.com/elementchen/VoxTriple_Classic/releases/tag/v1.0.10)；
   * 在「Assets / 资源列表」中下载以下三个文件：
     1. **`esp32_bt_mic_merged_v1.0.10.bin`** —— **一键完整出厂镜像**（专门用于全新开发板的首次初始化烧录）。
     2. **`esp32_bt_mic_v1.0.10.bin`** —— **常规应用固件**（用于后续在桌面配置客户端中一键极速 OTA 升级）。
     3. **`VoxTripleConfig.exe`** —— **Windows 配置与升级客户端**（绿色免安装单文件版）。
3. **准备硬件**：
   * 一块 NodeMCU-32S (ESP32-WROOM-32) 开发板。
   * 一根支持数据传输的 Micro-USB 或者是 Type-C 串行线缆（注意：请不要使用只能充电的纯电源线，否则电脑会识别不到端口）。

---

## ⚡ 第二部分：全新开发板首次烧录（小白一键引导）

如果您的开发板是一块刚买来的新板子，或者之前烧录过别的不相干程序，请使用本节方法进行首次出厂烧录：

1. **接线并连接电脑**：
   * 用 USB 数据线将 ESP32 开发板插到 Windows 电脑的 USB 接口上。
2. **运行乐鑫烧录工具**：
   * 打开第一步中解压好的文件夹，双击运行 **`flash_download_tool_x.x.x.exe`**。
   * 在弹出的选择框中，分别选择以下选项：
     * **Chip Type / 芯片类型**：选择 **`ESP32`**
     * **Work Mode / 工作模式**：选择 **`develop`**
     * 点击 **`OK`** 进入主烧录界面。
3. **配置一键合并固件（极其重要）**：
   * 勾选第一行最左侧的复选框，使其亮起；
   * 点击第一行右侧的 **`...`** 按钮，在弹出的文件浏览器中选择您刚才下载的 **`esp32_bt_mic_merged_v1.0.10.bin`**；
   * 在它右侧的 **`@`** 符号后面的输入框中，输入数值：**`0x0`**（这就是唯一的烧录偏置地址，其余三行全部留空！）。
4. **底层配置项检查（保持默认即可）**：
   * **SPI SPEED**：`40MHz`
   * **SPI MODE**：`DIO`
   * **FLASH SIZE**：`32Mbit` (即 4MB，这是最通用的出厂配置)
5. **选择电脑串口**：
   * 在主界面最下方的 **`COM`** 下拉框中，选择您开发板对应的串口（如 `COM5`，如果您分不清是哪一个，可以拔掉 USB 再插上，看下拉框中哪个 COM 号消失了又出现，那就是它）；
   * 在 **`BAUD`（波特率）** 下拉框中，选择 **`115200`**（为了彻底隔绝阻抗噪声和电路抖动，建议新手在此波特率下烧录，非常稳健）。
6. **开始一键烧录**：
   * 确认前面的复选框已勾选，地址填的是 `0x0`，点击左下角的 **`START`** 按钮；
   * **💡 贴心小提示**：对于有些开发板，如果点击 `START` 后一直显示 `等待上电同步 / Waiting for sync`，请用手指**长按开发板上的 IO0 按键（通常标有 BOOT 字样）** 1-2秒，即可瞬间触发自动烧录；
   * 当界面上出现绿色的 **`FINISH`（完成）** 字样时，说明您的开发板已经完成了出厂初始化，您的四键蓝牙键盘麦克风系统已经正式跑起来了！

---

## 🔄 第三部分：日常一键智能升级固件（全新全自动流程）

一旦您的开发板通过第二步运行了我们的固件，今后如果官方发布了新版本（例如云端推出了新版 `1.0.11`，而您的板子上运行的是 `1.0.10`），您**完全不需要**再次使用复杂的 Flash 工具或长按 Boot 键。只需直接使用我们的配置 App，即可享受全自动检测、自动下载和 20 秒极速 OTA 有线升级：

### 智能升级步骤（首选）：
1. **连接您的开发板**：
   * 运行 **`VoxTripleConfig.exe`**；
   * 在最上方的串口下拉框选择开发板串口并点击「Connect / 连接」。
2. **全自动在线版本检测**：
   * 连上后，App 会自动从开发板读取当前版本号，并与 GitHub 官方发布的最新的版本号进行比对：
     * **若已经是最新版**：在顶部固件版本号旁边会静默亮起绿字 `(已经是最新版固件)`。
     * **若有更新版本**：在顶部版本号旁会**醒目浮现出一个「Update / 升级固件」按钮**，并用小字写上最新版本（如 `(最新版: 1.0.11)`）。
3. **一键 Cloud Update 闪电升级**：
   * 您只需直接点击顶部的那个**「Update / 升级固件」**按钮；
   * 软件会**全自动切换**到固件升级选项卡（Tab 2），并开启自动升级流程：
     * **自动下载**：App 会在后台自动从 GitHub 极速下载最新版的应用固件，并在进度条上实时展示下载百分比；
     * **自动写入**：下载完成的一瞬间，进度条归零，并开始展示 20 秒有线直写 OTA 进度。
     * **软重启**：写入完毕后，软件提示“升级成功”，开发板会自动软重启并跑在最新固件上。配置 App 会自动安全断开，此时您只需重新连接串口即可！

### 💾 网络不好？使用离线缓存升级：
如果您的电脑网络不佳，在点击升级按钮后反复下载失败，您可以通过以下方式“手动离线升级”：
1. **新建 `cache` 缓存文件夹**：
   * 在您配置 App（`VoxTripleConfig.exe`）所在的同级目录下，新建一个名字叫 **`cache`** 的文件夹；
2. **手动下载固件并放入**：
   * 用其它方式（如手机或浏览器）从 GitHub 下载最新发布的应用固件 `.bin`（例如 [esp32_bt_mic_v1.0.10.bin](https://github.com/elementchen/VoxTriple_Classic/releases/download/v1.0.10/esp32_bt_mic_v1.0.10.bin)）；
   * 将该二进制文件放入您刚才建立的 `cache` 目录下，并重命名为对应版本格式（如 **`cache/esp32_bt_mic_v1.0.10.bin`**）；
3. **点击升级**：
   * 连上串口后点击「Update / 升级固件」按钮。App 在检测本地缓存时会发现该文件已经存在，将**直接跳过网络下载阶段**，瞬间开启 20 秒极速有线 OTA 写入！

---

## 🔑 第四部分：常见问题与排查指南

* **Q：为什么我的电脑插上 USB 线后，烧录工具和配置 App 的下拉框里找不到 COM 串口？**
  * **A**：有两种可能：① 您使用的是纯充电的电源线，请更换能传输数据的 Micro-USB / Type-C 数据线；② 您的电脑缺少串口芯片驱动（开发板常用 CH340 或 CP2102 芯片），请在网上搜索下载并安装对应的 Windows CH340 驱动程序，即可在设备管理器中显示出端口。
* **Q：为什么物理按键在 App 里可以监测到按下，但电脑却没有打字响应？**
  * **A**：配置 App 是配置通道。在配置结束后，您必须让开发板与电脑建立**经典蓝牙（Classic Bluetooth）**配对！请打开 Windows 设置 ➡️ 添加蓝牙设备 ➡️ 搜索并配对 `VoxTriple_Classic`。配对成功后，蓝牙键盘和音频输入设备就会由系统自动装载就绪，您就可以正常使用了！

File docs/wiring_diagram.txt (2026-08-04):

================================================================================
                    ESP32 蓝牙麦克风项目 - 接线图
================================================================================

开发板: WEMOS ESP32 Board with 18650 Battery Holder
麦克风: INMP441 全向麦克风模块 (MEMS I2S)
按钮: 4个轻触按键 (GND有效，内部上拉)
板载指示灯: 固化在 GPIO 16 (低电平有效，0: 亮, 1: 灭)

================================================================================
                              接线图
================================================================================

    ┌─────────────────────┐              ┌─────────────────────┐
    │     WEMOS ESP32     │              │      INMP441        │
    │                     │              │                     │
    │  3.3V (左侧排 Pin 1)┼──────────────┼── VDD               │
    │                     │              │                     │
    │  GND  ─────────────┼──────────────┼── GND               │
    │                     │              │                     │
    │  GPIO 17 ──────────┼──────────────┼── SD (I2S DATA)     │
    │                     │              │                     │
    │  GPIO 22 ──────────┼──────────────┼── WS (I2S LRCK)     │
    │                     │              │                     │
    │  GPIO 21 ──────────┼──────────────┼── SCK (I2S BCLK)    │
    │                     │              │                     │
    │                GND ─┼──────────────┼── L/R (接地选择左声道)│
    │                     │              │                     │
    └─────────────────────┘              └─────────────────────┘

================================================================================
                              按钮接线
================================================================================

    ┌─────────────────────┐              ┌─────────────────────┐
    │     WEMOS ESP32     │              │       按钮          │
    │                     │              │                     │
    │  GPIO 4 ────────────┼──────────────┼── Button 1 (语音PTT / RTC唤醒键)
    │                     │              │         │           │
    │  GND  ──────────────┼──────────────┼─────────┘           │
    │                     │              │                     │
    │  GPIO 18 ───────────┼──────────────┼── Button 2 (普通快捷键)
    │                     │              │         │           │
    │  GND  ──────────────┼──────────────┼─────────┘           │
    │                     │              │                     │
    │  GPIO 19 ───────────┼──────────────┼── Button 3 (普通快捷键)
    │                     │              │         │           │
    │  GND  ──────────────┼──────────────┼─────────┘           │
    │                     │              │                     │
    │  GPIO 23 ───────────┼──────────────┼── Button 4 (蓝牙配对清除键)
    │                     │              │         │           │
    │  GND  ──────────────┼──────────────┼─────────┘           │
    │                     │              │                     │
    └─────────────────────┘              └─────────────────────┘

注意: 按钮按下时接地(GND)，释放时为高电平。使用内部上拉电阻。

================================================================================
                              板载指示灯
================================================================================

开发板自带的蓝色贴片指示灯物理连接在 GPIO 16 上。
* 无需任何外部接线与电阻。
* 低电平有效 (Active Low)：
  - 熄灭：代码向 GPIO 16 输出高电平 (1)；
  - 点亮：代码向 GPIO 16 输出低电平 (0)；
* 工作行为：
  - 冷启动或从深度睡眠中唤醒时，指示灯快速闪烁 3 次作为物理连接反馈；
  - 待机与休眠状态下，指示灯保持完全熄灭，避免漏电；
  - 当按下 Button 1（语音键）进行说话传输时，指示灯常亮，释放时自动熄灭。

================================================================================
                              引脚分配表
================================================================================

┌──────────────┬──────────────┬──────────────┬──────────────┐
│   ESP32引脚  │  INMP441引脚 │    功能      │    说明      │
├──────────────┼──────────────┼──────────────┼──────────────┤
│    3.3V      │     VDD      │    电源      │  3.3V供电    │
│    GND       │     GND      │    地        │  公共地      │
│    GPIO 17   │     SD       │  I2S数据输入 │  音频数据    │
│    GPIO 22   │     WS       │  I2S字选择   │  帧同步      │
│    GPIO 21   │     SCK      │  I2S时钟     │  位时钟      │
│    GND       │     L/R      │  左/右声道   │  接地=左声道  │
└──────────────┴──────────────┴──────────────┴──────────────┘

┌──────────────┬──────────────┬──────────────┬──────────────┐
│   ESP32引脚  │    按钮      │    功能      │    说明      │
├──────────────┼──────────────┼──────────────┼──────────────┤
│    GPIO 4    │  Button 1    │ PTT语音/唤醒键│  支持RTC唤醒 │
│    GPIO 18   │  Button 2    │  普通快捷键  │  内部上拉    │
│    GPIO 19   │  Button 3    │  普通快捷键  │  内部上拉    │
│    GPIO 23   │  Button 4    │ 蓝牙配对清除键│  长按3秒清除 │
└──────────────┴──────────────┴──────────────┴──────────────┘

================================================================================

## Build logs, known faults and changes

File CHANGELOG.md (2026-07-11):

# Changelog

## v2.4-dual-mode-reconnect-fix (2026-06-19)

> 双模共存（经典蓝牙 HFP 麦克风 + BLE 键盘）完美自动重连版本。设计了双本端 MAC 真假隔离方案，并通过将 BLE 配对参数调整为 Legacy Pairing（禁用 CTKD），成功消除了在对端 MAC 重合时引起的 NVS 绑定密钥覆盖与畸变 Bug。

### 修复与优化
- **双 MAC 精准物理隔离**：本端经典蓝牙 HFP 麦克风使用 efuse 真实物理 MAC 地址，BLE 键盘则通过微调物理 MAC 使用独立的静态随机 MAC 地址。规避了因本端 MAC 地址相同被 Windows 合并的冲突。
- **回退至 Legacy Pairing 禁用 CTKD**：在 `ble_gatts_config.c` 中将配对要求设为 `ESP_LE_AUTH_BOND`。禁用跨传输层密钥派生（CTKD），从根本上消除了重启时对端 MAC 密钥的覆盖冲突，防止了 LTK (`PENC`) 的抹去（key_mask 不再畸变退化为 `0x89`），彻底消除了 MIC Failure 0x3d 引起的闪退与删绑故障。

---

## v2.2-nimble-stable (2026-06-19)

> 纯 NimBLE BLE 键盘完美自动秒连版本。解决了首次连接识别为 NIMBLE、冷置 LMP 自动断连、重启回连失效与启动卡死三大重连核心故障，为后续双模演进建立了可靠的设计基准。

### 修复与优化
- **首次连接识别修复**: 显式配置 GATT GAP Device Name 和 Appearance。解决设备首次在 Windows 蓝牙列表中显示为 `NIMBLE` 且图标类型错误的底层逻辑缺陷。
- **冷置 LMP 连接超时修复 (reason=546)**: 运行时强制禁用 Modem Sleep 且在控制器中关闭休眠，避免控制器切换为 150kHz 低精度 RC 时钟导致的连接时隙对齐失败（温飘丢包）。
- **重启回连失效与 573 闪退修复 (MIC Failure)**: 强制开启非对称密钥分配，保留并声明对端及本端 `ENC_KEY` 的分发标志，解决 Windows 丢弃绑定信息与解密计数器错位闪断问题。
- **启动无广告修复**: 调整全局 `ble_hs_cfg` 的回调注册时序，防止被 `esp_hid_gap_init` 底层覆盖清空导致广告无广播启动。

---

## v1.3-stable (2026-05-19)

> GPIO pinout reworked for cleaner wiring and antenna interference avoidance. Dynamic device name. BLE-triggered HFP auto-reconnect retained.

### Firmware
- **Dynamic device name**: `ESP32_BT_MIC_XX` where `XX` is the last byte of the Bluetooth MAC address
  - Allows multiple boards to coexist with distinguishable names
  - `g_bt_device_name` shared between Classic BT (`bt_init.c`) and BLE advertising (`ble_gatts_config.c`)
- **GPIO pinout reworked** — sensitive I2S DATA moved to left side away from PCB antenna; clock/control on right
  - Left (away from antenna): Button 1=GPIO 16, Button 3=GPIO 18, I2S DATA=GPIO 17
  - Right: WS=GPIO 33, SCK=GPIO 25, LED=GPIO 26, Button 2=GPIO 14
  - Eliminates RF interference from high-speed I2S data line near antenna
- **Bluetooth TX power**: set to +3dBm (`ESP_PWR_LVL_P3`) for stable indoor range
- **BLE-triggered HFP auto-reconnect**: on BLE connect, auto-reconnect Classic HFP to last paired Windows device
  - `config_storage` NVS blob for HFP peer address persistence
  - `bt_hfp_hf_wake_acl()` via internal `BTM_SetPowerMode()` API to exit sniff on button press
- **Windows pairing note**: if audio stops working after pinout changes, delete the Bluetooth microphone device in Windows and re-pair

----

## v1.2-stable (2026-05-15)

> Audio pipeline refactored: continuous operation across SCO cycles. Log output reduced. WS2812 removed (RMT/BT conflict). Sniff-mode mitigation via ACL wake on button press.

### Firmware
- **Audio pipeline refactored**: starts on HFP SLC connect, runs continuously across SCO cycles
  - No per-cycle ringbuf/task/timer create/delete — eliminates "invalid air mode: 255" corruption
  - `outgoing_data_ready()` guarded by `bt_audio_is_active()` to prevent dead-SCO calls
  - Ring buffer flush on SCO open prevents cross-session audio bleed
- **Log suppression**: `esp_log_level_set("*", ESP_LOG_WARN)` after init — only WARN/ERROR on serial
- **Sniff mitigation**: `CONFIG_BTDM_CTRL_MODEM_SLEEP=n` + `BTM_SetPowerMode(ACTIVE)` on button press
  - Reduces SCO open latency; partial fix (sniff still enters after ~7s idle, ~500ms re-activation)
- **WS2812 removed**: eliminated RMT/BT conflict causing `ws2812_anim` stack overflow & reboot
- **BLE conn params fix**: `remote_bda` copied from `ESP_GATTS_CONNECT_EVT` into `conn_params`

### Known limitations
- `invalid air mode: 255` appears once per SCO disconnect — benign Bluedroid race, does not affect function
- HFP ACL still enters sniff after ~7s idle; button wake reduces but doesn't eliminate SCO latency
- First ~2-3 characters may still be lost when speaking after long silence

----

## v1.1-stable (2026-05-13)

> Simplified architecture: buttons only send BLE keyboard events, HFP audio fully managed by Windows AG. Zero task_wdt crashes.

### Firmware
- **Architecture simplified**: buttons no longer control SCO audio — only send BLE keyboard events
  - HFP pipeline always ready, Windows AG manages audio start/stop
  - Eliminates all BTU_TASK task_wdt deadlocks
- **BTU_TASK fix**: audio pipeline work deferred to app task via `bt_app_work_dispatch`
- **BLE fast connection**: request `conn_int=12-24` (15-30ms) for low-latency keyboard events
- **WS2812 rainbow restored**: 4 LEDs on GPIO 15, Button 1 press=start, release=stop
  - Hue limited to yellow-green-blue (60-240°), ping-pong gradient
  - Safe to run alongside Bluetooth — no RMT/BT conflict
- BLE connection interval forced to 15-30ms for low latency
- Audio send task priority lowered from 22 to 5

### Python App
- Keyboard simulation: `keybd_event` (pure VK codes, stable in all apps)
- BLE client: resolve characteristics by handle within service scope (fixes bleak UUID conflict)
- Key capture: pynput win32_event_filter, dispatched to tkinter main thread
- Single-file EXE: 11 MB PyInstaller output
- Auto-start on boot + auto-connect BLE on launch

### Docs
- README: full bilingual (English + Chinese)
- CHANGELOG.md: incremental version history
- Multi-device switching spec archived in docs/

### Windows C# App
- Archived to `_Archive/windows_app_csharp/`

----

## v1.0-stable (2026-05-10)

### Firmware
- **Simplified architecture**: buttons only send BLE keyboard events, no SCO control
  - HFP audio pipeline always ready, Windows AG manages SCO start/stop
  - Eliminates task_wdt crashes caused by SCO teardown in BTU_TASK
- **BTU_TASK starvation fix**: audio pipeline work deferred to app task via `bt_app_work_dispatch`
- **BLE fast connection**: request `conn_int=12-24` (15-30ms) for low-latency keyboard events
- **WS2812 rainbow restored**: 4 LEDs, Button 1 press=start, release=stop
  - Rainbow task safe now — no longer conflicts with SCO (buttons don't touch audio)
- Audio send task priority lowered from 22 to 5

### Python App
- **Keyboard simulation**: `keybd_event` (pure VK codes, no SCANCODE conflict)
- Windows C# app archived to `_Archive/`
- Python EXE rebuilt (11 MB)

----

## v1.0-stable (2026-05-10)

> Stable single-device release. All core features working reliably.

### Firmware
- HFP HF Client + mSBC 16kHz — Windows native Bluetooth microphone
- 3 buttons: configurable keyboard shortcuts via BLE GATT
- WS2812 LED strip (4 LEDs): rainbow on Button 1 press
- Legacy I2S driver for clean audio (INMP441)
- BLE GATT service 0x1820 with 5 characteristics
- BTDM dual-mode controller (SCO + BLE coexistence)
- Audio DSP: high-pass filter + moving average

### Windows App (C# WPF, archived)
- BLE scan (BluetoothLEAdvertisementWatcher), connect, GATT R/W
- Win32 key capture hook (bypasses IME, detects modifiers)
- keybd_event keyboard simulation
- Auto-start on boot, auto-connect BLE on launch

### Python App
- tkinter + bleak + pynput, independent alternative
- 11 MB PyInstaller single-file EXE

### Removed
- Multi-device switching (Button 4) — rolled back, spec archived in docs/

----

## 2026-05-10

### Multi-Device Switching & LED

- **新增 Button 4** (GPIO 27)：设备切换 + 配对管理
  - 短按 (<5s)：切换到下一个已配对设备，绿灯闪烁指示当前设备号
  - 长按 (≥5s, 不松手即触发)：清除当前设备配对记录并进入配对模式
  - 设备指示：1 次绿灯闪烁 = 设备 1 / 2 次 = 设备 2，各重复 3 轮
- **配对模式重写**
  - 蓝灯真正快闪（独立 FreeRTOS task），不再常亮
  - 非阻塞状态机，配对中可短按 Button 4 取消
  - 30s 超时蓝灯熄灭退出，不再亮红灯
  - HFP 连接成功自动保存设备地址到 NVS
- **PTT 增强**：BLE 未连接时按下 Button 1，红灯闪烁 3 次
- 新增 `config_storage` 设备列表 CRUD 函数，支持 2 设备 NVS 存储

### WS2812 LED

- 新增 `ws2812_device_indicator(dev_idx)`：N 次绿灯闪烁表示设备号
- 新增 `ws2812_blink_color()`：真正快闪（blink task）
- 修复 `ws2812_solid_color()` 不自动熄灭的 bug

----

## 2026-05-09

### Windows App — Key Capture & BLE Fixes

- **按键捕获改用 Win32 WM_KEYDOWN 钩子**（绕过 IME）
  - 捕获时临时关闭输入法，解决中文输入法 VK-E5 问题
  - Right Shift 改用扫描码 (0x36) 区分左右
  - Tab 键可捕获（`KeyboardNavigation.TabNavigation="None"` + `WM_GETDLGCODE`）
- **键盘模拟改用 `keybd_event`**（WiFi 项目验证方案），替代 `SendInput`
- **修饰键正确捕获**：左/右 Ctrl/Shift/Alt 自动区分（extended flag）
- **BLE 连接修复**
  - 扫描改用 `BluetoothLEAdvertisementWatcher` Active 模式
  - 连接改用 `BluetoothLEDevice.FromBluetoothAddressAsync()` 直连 MAC 地址
  - GATT 发现增加 3 次重试 + `BluetoothCacheMode.Uncached`
  - 连接后等待 1.5s 等服务注册完成
- **开机自动启动**：勾选框写入 Windows Startup 文件夹
- **开机自动连接 BLE**：首次 Scan & Connect 后记住地址，下次启动自动连
- **单文件 EXE 发布**：`dotnet publish -p:PublishSingleFile=true` → 25MB 单文件

### ESP32 固件 — 音质 + BLE 修复

- **I2S 驱动切换**：从新版 `i2s_std.h` 切换到旧版 `driver/i2s.h`
  - `use_apll = false`、`I2S_COMM_FORMAT_STAND_I2S`、`i2s_zero_dma_buffer()`
  - 音质大幅改善，消除电流噪音
- **I2S DMA 保持活跃**：SCO 断开时不真正停 I2S，解决二次连接挂死
- **BLE GATT 修复**
  - 广播数据拆分：广告包 (name+flags ≤31B) + 扫描响应包 (128-bit UUID)
  - 新增 `esp_ble_gatts_start_service()` 调用，修复服务不可见 bug
  - `GATTS_NUM_HANDLES` 12 → 16
  - Button Event 新增 CCCD 描述符
  - 修复 `s_conn_id == 0` 误判无连接 bug

### 音频降噪 DSP

- **高通滤波 (80Hz cutoff, 1-pole IIR)**：去除低频风噪、电路哼声
- **5-tap 滑动平均**：平滑高频数字毛刺
- 噪声门（默认禁用）

----

## 2026-05-07 — 2026-05-08

### HFP HF Client 重构

- **从 HFP AG 切换到 HFP HF Client**：Windows 正确识别为蓝牙麦克风
- BTDM SCO 致命配置修复：`CONFIG_BTDM_CTRL_BR_EDR_MAX_SYNC_CONN=1` 和 `SCO_DATA_PATH_HCI=y`
- CoD 更新：`service=0x340, major=0x04(Audio/Video), minor=0x02(Hands-free)`
- mSBC 16kHz 宽带语音编解码协商和音频管线
- **PTT (Button 1)**：按住开 SCO 音频、松开关闭
- I2S 音频路由优化：避免双重读取、ring buffer 9.6KB
- 出站回调欠载时返回静音而非 0，解决"哒哒哒"爆音

### Windows C# WPF 应用

- .NET 8 WPF + CommunityToolkit.Mvvm
- BLE GATT 客户端：扫描、连接、读写按钮映射
- KeyboardSimulator (Win32 SendInput)
- MVVM 架构 + JSON 配置持久化

### BLE GATT 服务

- 自定义服务 0x1820 + 5 个特征值
- Button 1-3 Map、Button Event (Notify)、Device Status (Notify)
- 广播数据 flags + 128-bit UUID + device name

### WS2812 LED

- GPIO 15, RMT 驱动, 15 颗灯珠
- PTT 按下 + BLE 连接时七彩循环

### Python tkinter 应用

- `windows_app_python/` 独立 Python 版本
- bleak BLE + pynput 按键捕获 + keybd_event 模拟
- tkinter GUI，11MB PyInstaller 单文件 EXE

### 文档

- GitHub README 中英双语
- MIT LICENSE
- 项目架构文档 + BLE 协议规范 + 接线图

----

## 2026-05-06 及之前

### 项目初始化

- ESP32 PlatformIO + ESP-IDF 项目骨架
- HFP AG 初始实现（后废弃）
- Windows WPF 应用初始版本
- 硬件接线文档

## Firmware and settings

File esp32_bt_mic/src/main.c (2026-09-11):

/*
 * SPDX-FileCopyrightText: 2024 ESP32 BT Microphone Project
 *
 * SPDX-License-Identifier: Unlicense OR CC0-1.0
 */

#include <stdio.h>
#include <stdlib.h>
#include <string.h>
#include "freertos/FreeRTOS.h"
#include "freertos/task.h"
#include "esp_system.h"
#include "esp_log.h"
#include "esp_bt.h"
#include "driver/gpio.h"
#include "sdkconfig.h"
#include "esp_wifi.h"
#include "nvs.h"
#include "nvs_flash.h"

#include "bt_init.h"
#include "audio_capture.h"
#include "button_handler.h"
#include "config_storage.h"
#include "classic_hidd.h"
#include "uart_console.h"
#include "bt_config.h"
#include "board_profile.h"

static const char *TAG = "MAIN";

void app_main(void)
{
    ESP_LOGI(TAG, "============================================");
    ESP_LOGI(TAG, "  ESP32 Bluetooth Microphone - PTT Mode");
    ESP_LOGI(TAG, "  HFP HF Client + BLE GATT Server");
    ESP_LOGI(TAG, "============================================");

    /* Step 1: Initialize NVS */
    ESP_LOGI(TAG, "Step 1: Initializing NVS...");
    ESP_ERROR_CHECK(bt_nvs_init());

    /* Step 2: Load saved configuration & Board Profile */
    ESP_LOGI(TAG, "Step 2: Loading configuration & Board Profile...");
    config_storage_init();
    board_profile_init();

    const board_profile_t *profile = board_profile_get_current();
    gpio_num_t led_pin = profile ? profile->led_gpio : GPIO_NUM_16;

    /* Drive indicator LED high immediately (OFF for active-low LED) */
    gpio_config_t led_cfg = {
        .pin_bit_mask = (1ULL << led_pin),
        .mode = GPIO_MODE_OUTPUT,
        .pull_up_en = GPIO_PULLUP_DISABLE,
        .pull_down_en = GPIO_PULLDOWN_DISABLE,
        .intr_type = GPIO_INTR_DISABLE,
    };
    gpio_config(&led_cfg);
    gpio_set_level(led_pin, 1); // 1 = OFF (Active Low)

    /* Check if we need to enter clean OTA mode */
    uint8_t ota_ready = 0;
    if (config_storage_load_ota_ready(&ota_ready) == ESP_OK && ota_ready == 1) {
        ESP_LOGW(TAG, "=========================================================");
        ESP_LOGW(TAG, "   DETECTED OTA READY FLAG! ENTERING PURE OTA MODE        ");
        ESP_LOGW(TAG, "   SKIPPING ALL BT, AUDIO, & GPIO INITIALIZATIONS        ");
        ESP_LOGW(TAG, "=========================================================");
        
        // 1. Initialize only Wired UART Console for firmware reception
        ESP_ERROR_CHECK(uart_console_init());
        
        // 2. Light up board LED to show visual OTA indication (0: ON)
        gpio_set_level(led_pin, 0); // ON (Active Low)
        
        // 3. Keep main task idle while UART receives firmware
        while (1) {
            vTaskDelay(pdMS_TO_TICKS(1000));
        }
    }

    /* Dump NVS bt_config namespace */
    ESP_LOGI(TAG, "Dumping all NVS entries:");
    nvs_iterator_t it = NULL;
    esp_err_t err = nvs_entry_find("nvs", NULL, NVS_TYPE_ANY, &it);
    if (err != ESP_OK || it == NULL) {
        ESP_LOGI(TAG, "  No entries found in NVS partition 'nvs'");
    }
    while (it != NULL) {
        nvs_entry_info_t info;
        nvs_entry_info(it, &info);
        ESP_LOGI(TAG, "  NS: %s, Key: %s, Type: 0x%02X", info.namespace_name, info.key, info.type);
        err = nvs_entry_next(&it);
        if (err != ESP_OK) {
            it = NULL;
        }
    }

    /* Read and print bt_cfg_key0 */
    nvs_handle_t handle;
    if (nvs_open("bt_config.conf", NVS_READONLY, &handle) == ESP_OK) {
        size_t size = 0;
        if (nvs_get_blob(handle, "bt_cfg_key0", NULL, &size) == ESP_OK && size > 0) {
            char *buf = malloc(size + 1);
            if (buf) {
                if (nvs_get_blob(handle, "bt_cfg_key0", buf, &size) == ESP_OK) {
                    buf[size] = '\0';
                    ESP_LOGI(TAG, "Content of bt_cfg_key0 (size=%d):", size);
                    /* Print in chunks if it is too long for ESP_LOG */
                    for (int i = 0; i < size; i += 256) {
                        printf("%.256s", buf + i);
                    }
                    printf("\n");
                }
                free(buf);
            }
        }
        nvs_close(handle);
    }

    /* Step 3: Initialize I2S microphone driver */
    ESP_LOGI(TAG, "Step 3: Initializing I2S microphone...");
#if ENABLE_CLASSIC_BT_MIC
    ESP_ERROR_CHECK(audio_capture_init());
#else
    ESP_LOGI(TAG, "I2S microphone skipped (Classic BT disabled)");
#endif

    /* Step 4: Initialize Bluetooth stack (dual mode: BTDM) */
    ESP_LOGI(TAG, "Step 4: Initializing Bluetooth stack...");
    ESP_ERROR_CHECK(bt_stack_init());

    /* Force disable BT sleep mode (Modem Sleep) in runtime to prevent connection timeouts (reason 546) and MIC failures */
    esp_bt_sleep_disable();
    ESP_LOGI(TAG, "BT sleep mode disabled by force");

    /* Disable WiFi to save power — we only use Bluetooth */
    esp_err_t wifi_ret = esp_wifi_stop();
    if (wifi_ret == ESP_OK) {
        esp_wifi_deinit();
        ESP_LOGI(TAG, "WiFi disabled for power saving");
    }

    /* Step 5: Initialize Classic BT HID Keyboard */
    ESP_LOGI(TAG, "Step 5: Initializing Classic BT HID Keyboard...");
    ESP_ERROR_CHECK(classic_hidd_init());

    /* Step 5b: Initialize Wired UART Console Config */
    ESP_LOGI(TAG, "Step 5b: Initializing Wired UART Console Config...");
    ESP_ERROR_CHECK(uart_console_init());

    /* Step 6: Initialize button handler */
    ESP_LOGI(TAG, "Step 6: Initializing button handler...");
    button_handler_init();

    ESP_LOGI(TAG, "============================================");
    ESP_LOGI(TAG, "  System initialized successfully!");
    ESP_LOGI(TAG, "  Waiting for Bluetooth connections...");
    ESP_LOGI(TAG, "============================================");

    /* Restore INFO logging for debugging BT stack state and connection event flow. */
    esp_log_level_set("*", ESP_LOG_INFO);
    esp_log_level_set("BTN_HANDLER", ESP_LOG_DEBUG);
    esp_log_level_set("CLASSIC_HIDD", ESP_LOG_DEBUG);
    esp_log_level_set("BT_BTM", ESP_LOG_DEBUG);
    esp_log_level_set("BT_GAP", ESP_LOG_DEBUG);
    esp_log_level_set("BT_HCI", ESP_LOG_DEBUG);
    esp_log_level_set("BT_APPL", ESP_LOG_DEBUG);
    esp_log_level_set("BT_BTC", ESP_LOG_DEBUG);

    /* Main task done - other tasks handle everything */
    while (1) {
        vTaskDelay(pdMS_TO_TICKS(1000));
    }
}

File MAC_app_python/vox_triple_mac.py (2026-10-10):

#!/usr/bin/env python3
from __future__ import annotations
"""VoxTriple — ESP32 BT Microphone Config (macOS - Webview Edition)

Shares spp_client.py with the Windows version.
Punctuation and keystrokes are captured natively in Webview via JS to avoid system crashes.
Wired config and OTA firmware flashing are handled via physical USB Serial.
"""
import sys
import os
import asyncio
import logging
import urllib.request
import json
import threading
import webview
import serial.tools.list_ports
import subprocess

# Import shared modules from sibling windows_app_python directory
_shared = os.path.join(os.path.dirname(__file__), "..", "windows_app_python")
if os.path.isdir(_shared):
    sys.path.insert(0, os.path.abspath(_shared))

import spp_client

logging.basicConfig(level=logging.INFO, format="%(asctime)s [%(name)s] %(message)s")
log = logging.getLogger("VoxTriple")

# ── Async background loop ──────────────────────────────────────────
_loop: asyncio.AbstractEventLoop | None = None
_thread: threading.Thread | None = None

def start_asyncio_loop():
    global _loop
    _loop = asyncio.new_event_loop()
    asyncio.set_event_loop(_loop)
    _loop.run_forever()

def run_coro(coro):
    if _loop is None:
        return None
    return asyncio.run_coroutine_threadsafe(coro, _loop)

# ── Webview Python JS-Bridge API ───────────────────────────────────────
class Api:
    def __init__(self):
        self.spp = spp_client.SppClient()
        self.spp.on_button_event = self._on_button_event
        self.spp.on_status = self._on_status
        self._connected = False
        self._window = None
        self._github_version = None
        self._github_bin_url = None

    def set_window(self, window):
        self._window = window

    def get_ports(self) -> list[str]:
        """Scan Mac local for USB Serial ports, filter out virtual bluetooth ports."""
        ports = []
        for p in serial.tools.list_ports.comports():
            if "Bluetooth" not in p.device:
                ports.append(p.device)
        return ports

    def connect_device(self, port: str) -> bool:
        """Connect to physical USB-serial device."""
        log.info(f"Connecting to {port}...")
        future = run_coro(self.spp.connect(port))
        ok = future.result(timeout=6.0)
        self._connected = ok
        return ok

    def disconnect_device(self) -> bool:
        """Disconnect current device."""
        log.info("Disconnecting serial port...")
        future = run_coro(self.spp.disconnect())
        future.result(timeout=3.0)
        self._connected = False
        return True

    def fetch_config(self) -> dict | None:
        """Fetch config cache from the device."""
        if not self._connected:
            return None
            
        future = run_coro(self.spp._fetch_config())
        ok = future.result(timeout=3.0)
        if not ok:
            return None
            
        # Format mapping list to JSON compatible
        config = {
            "version": self.spp._config_cache.get("version", "1.0.17"),
            "tx_power": self.spp._config_cache.get("tx_power", 4),
            "sleep_mode": self.spp._config_cache.get("sleep_mode", 1),
            "mic_enabled": self.spp._config_cache.get("mic_enabled", 1),
            "board_model": self.spp._config_cache.get("board_model", 0),
            "board_name": self.spp._config_cache.get("board_name", "WEMOS 18650"),
            "sleep_timeout_min": self.spp._config_cache.get("sleep_timeout_min", 5),
            "mappings": []
        }
        for i in range(4):
            vk = self.spp._config_cache.get(f"btn{i+1}_vk", 0)
            mod = self.spp._config_cache.get(f"btn{i+1}_mod", 0)
            config["mappings"].append({"vk": vk, "mod": mod})
            
        return config

    def write_config(self, mappings: list, tx: int, sleep: int, mic: int) -> bool:
        """Write all parameters to board Flash at once."""
        if not self._connected:
            return False
            
        log.info(f"Save parameters: mapping={mappings}, tx={tx}, sleep={sleep}, mic={mic}")
        future = run_coro(self.spp.set_config(mappings, tx, sleep, mic))
        ok = future.result(timeout=5.0)
        return ok

    def set_board_model(self, model: int) -> dict:
        """Set board hardware model on device and trigger restart."""
        if not self._connected:
            return {"success": False, "message": "Not connected"}
        log.info(f"Set board hardware model: {model}")
        future = run_coro(self.spp.write_board_model(model))
        ok = future.result(timeout=5.0)
        return {"success": ok, "message": "ok" if ok else "write failed"}

    def set_sleep_timeout_min(self, minutes: int) -> dict:
        """Set inactivity sleep timeout (minutes) on device and trigger restart."""
        if not self._connected:
            return {"success": False, "message": "Not connected"}
        log.info(f"Set sleep timeout: {minutes} min")
        future = run_coro(self.spp.write_sleep_timeout_min(minutes))
        ok = future.result(timeout=5.0)
        return {"success": ok, "message": "ok" if ok else "write failed"}

    def reset_bt_pairing(self) -> dict:
        """Expose API to frontend to forget BT pairings on the device and reboot."""
        if not self.spp or not self._connected:
            return {"status": "error", "message": "Device not connected"}
        future = run_coro(self.spp.reset_bt_pairing())
        try:
            ok = future.result(timeout=4.0)
            if ok:
                return {"status": "ok"}
            return {"status": "error", "message": "Command rejected"}
        except Exception as e:
            return {"status": "error", "message": str(e)}

    def select_local_bin(self) -> str | None:
        """Select a local firmware file using macOS Finder dialog (via AppleScript to bypass Frameless Sandboxing)."""
        log.info("Opening Finder file selection dialog...")
        script = 'POSIX path of (choose file of type {"bin"} with prompt "Select VoxTriple firmware file (.bin):")'
        try:
            res = subprocess.run(
                ["osascript", "-e", script], 
                capture_output=True, 
                text=True, 
                timeout=30.0
            )
            if res.returncode == 0:
                path = res.stdout.strip()
                log.info(f"User selected file via AppleScript Finder: {path}")
                return path
        except Exception as e:
            log.warning(f"AppleScript file dialog failed: {e}, falling back to native webview dialog")
            
        # Fallback to standard webview dialog
        if self._window:
            file_types = ('Firmware Files (*.bin)', '*.bin')
            res = self._window.create_file_dialog(webview.OPEN_DIALOG, file_types=file_types)
            if res and len(res) > 0:
                return res[0]
        return None
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

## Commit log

2026-06-19 fix: 解决双模重连闪断配对丢失与经典蓝牙开机广播泄漏 (D6/D7 MAC独立与密钥隔离)
    [button_handler.c, main.c]
2026-06-19 fix: 采用非对称密钥分发支持 Windows RPA 解析，调大连接 Latency=4 解决共存崩溃
2026-06-19 feat: 引入 ENABLE_CLASSIC_BT_MIC 诊断宏，默认完全隔离经典蓝牙进行重连排查
2026-06-19 fix: 对齐物理层 MAC 地址，仅修改最高字节为 0xC0，后 5 字节保持一致
2026-06-19 fix: 恢复非对称密钥分发，阻止向对端分发 ID_KEY，从根本上杜绝 Windows 底层双模同 MAC 强制合并与重连冲突
2026-06-19 fix: 注释掉连接建立时的立即参数更新请求，防止与 Windows 侧重连加密握手冲突导致闪断
2026-06-19 fix: 暂时异或 2 修改 BLE MAC 地址至 C0:03:2A:68:6B:D4 -> D6，彻底绕过 Windows 侧旧 MAC 地址配对缓存锁死，以此建立干净的配对重连基线
2026-06-19 fix: 解决已配对连接加密冲突闪断。对已绑定设备重连拦截 GATTS_CONNECT_EVT 发送给 esp_hid，延后至认证成功后补发，防止双向主动加密冲突
2026-06-19 debug: add bonded device printing on GATTS_INIT and AUTH_CMPL to trace key loss
2026-06-19 fix(ble): resolve app_id conflict and add 500ms deferred connection timer
    [main.c]
2026-06-19 fix(bt): use BLE-only controller when Classic BT disabled - prevents cross-transport key derivation causing Device not found
2026-07-12 feat(ota,ui): implement robust 20s wired OTA upgrade & refactor Windows/macOS native layout
    [partitions.csv]
2026-08-02 feat: map indicator LED to Button 1 pressed and released states
    [key_test.stl, main_box_slim.skp, main_box_thin.skp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]
2026-08-02 feat: re-map deep sleep wakeup, reconnection, and LED control to Button 2
2026-08-02 feat: keep external LED on Button 1 (speech) and sleep/reconnect triggers on Button 2
2026-08-03 feat: implement adaptive sleep mode to address power consumption and prevent key trigger in sleep
    [button_handler.c]
2026-08-03 feat: swap buttons to GPIO 4 and 18, set indicator LED on GPIO 16 (onboard), implement NVS mic toggle and remove sleep switch
    [button_handler.c, spp_client.py, vox_triple.py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]
2026-08-03 fix: invert indicator LED levels for Active-Low board hardware compatibility
    [button_handler.c]
2026-08-03 fix: replace __file__ with SPECPATH in VoxTriple_mac.spec to avoid NameError under PyInstaller
    [main_box_矮轴.skp]
2026-08-04 docs: update README and docs (wiring, flashing, architecture) to match WEMOS ESP32 pinout and version 1.0.10
    [main_box_矮轴.skp]
2026-08-04 fix: resolve pynput import crash and add standalone CLI compilation target to GitHub Actions macOS build
    [keyboard_io_mac.py]
2026-08-07 bump: revert version definitions to v1.0.9 for user request build and flash
    [main_box_矮轴.skp]
2026-08-07 fix: restore CMake project version to v1.0.10 and handle GitHub API rate limit 403 gracefully in clients
    [vox_triple.py, vox_triple_mac.py]
2026-08-09 feat(ota): add switchable OTA update modes supporting CP2102 classic sync and CH340 fast damping
2026-08-09 feat(ota): suspend audio DMA and Bluetooth RF stack during flashing to eliminate CPU Cache conflicts and flash write failures
    [uart_console.c]
2026-08-09 feat(ota): update spp_client.py classic mode to 16KB strict synchronization and auto clean-reboot support
    [main.c, spp_client.py, uart_console.c]
2026-08-09 fix(client): await disconnect to release com port, and set classic mode delay to 18ms to avoid uart overflow
    [spp_client.py]
2026-08-09 fix(client): implement trailing chunk confirmation filtering loop in final ota status query
    [spp_client.py]
2026-08-09 fix(client): add 0.5s drain delay for trailing bytes to prevent final ota chunk loss
    [spp_client.py]
2026-08-09 fix(client): sync previous ota blocks before emitting fractional tail chunk to avoid hardware rx overrun
    [spp_client.py]
2026-08-09 revert(client): restore classic sync mode to strict 1KB handshake for zero-load clean ota reliability
    [spp_client.py]
2026-08-09 fix(ota): increase uart_read_bytes timeout to 50ms to buffer ota blocks and reduce flash write fragmentation
    [uart_console.c]
2026-08-09 fix(client): implement regex ota status recovery from noisy serial lines, and set delay to 10ms
    [spp_client.py]
2026-08-09 refactor(client): use 4KB flash sector aligned sync to prevent windows driver lockup while preventing overruns
    [spp_client.py]
2026-08-09 fix(client): increase delay to 30ms and timeout to 10s to survive block erase and voltage ripples
    [spp_client.py]
2026-08-09 refactor(client): decrease chunk_size to 256 bytes to prevent packet-level UART overflow during block erase
    [spp_client.py]
2026-08-09 fix(client): align sync targets to 1KB multiples to match esp32 ota progress reporting boundaries
    [spp_client.py]
2026-08-10 feat(mac): release stable mac app v1.0.13 with non-crash keyboard capture and optimized serial ota flow control
    [keyboard_io_mac.py, vox_triple_mac.py]
2026-08-11 fix(mac): map Tkinter punctuation keysyms to correct Windows VK codes to resolve punctuation mapping mismatch
    [keyboard_io_mac.py]
2026-08-12 style(mac): adjust window size to prevent layout cuts and close debug console window on start
    [vox_triple_mac.py]
2026-08-12 style(mac): implement frameless window with draggable titlebar, custom close btn and live key monitoring
2026-08-12 fix(mac): resolve exit deadlock crash via os._exit and shrink window height to 800px to squeeze white spaces
    [vox_triple_mac.py]
2026-08-12 feat(mac): implement applescript fallback for Finder popup to fix frameless sandboxing dialog issue, and support smart cloud update with double progress indicators
    [vox_triple_mac.py]
2026-08-12 feat(mac): implement conditional rendering of UPDATE button and status label in connection bar to 100% align with old stable app behaviors
2026-08-12 feat(mac): restore WRITE CONFIG button and support real-time compound key combination text render upon capturing or toggling modifiers
2026-08-12 fix(mac): resolve modifier pill click mismatch bug by formatting mask to hex string and move WRITE TO ESP32 button below power saving card
2026-08-12 style(mac): change WRITE TO ESP32 button style to orange with transparent wrapper, increase window height to 860px to prevent bottom squeeze, and style close button to mimic native macOS traffic ligh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
    [vox_triple_mac.py]
2026-08-12 style(mac): scale down window default height to 780px to prevent titlebar/traffic lights from being obscured by system menu bar on smaller MacBook monitors
    [vox_triple_mac.py]
2026-08-12 feat(client): align windows client UI styling with macOS web client card-based aesthetics, using flat tk.Buttons and Emoji connection dot
2026-09-11 fix(client): support modifier key capturing in webview and resolve native file dialog thread block via Tkinter filedialog
    [vox_triple.py]
2026-09-11 docs: add dual-board hardware and firmware adaptation plan for ESP32 Lite V1.0.0
2026-09-11 feat: 支持 ESP32 Lite V1.0.0 与 WEMOS 18650 双硬件开发板兼容架构与客户端型号切换
    [ESP32_KeyBoard.skp, KeyBase.skp, cover.skp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]
2026-09-11 feat: 新增可配置深度休眠等待时间功能，默认5分钟（支持1~120分钟范围），覆盖固件NVS存储、SPP协议命令和客户端UI选择器
2026-09-13 feat: 适配 ESP32 Lite V1.0.0 优化按键排列 (GPIO 4/19/23/18)，升级发布 v1.0.15
    [ESP32_KeyBoard.skp, test0.stl, test0_temp.3mf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]
2026-09-13 fix(firmware): 全面校准默认按键引脚映射为 Button 1: 4, Button 2: 19, Button 3: 23, Button 4: 18 并设为出厂默认
    [board_profile.c, button_handler.c]
2026-09-13 refactor(firmware): 恢复出厂默认激活 WEMOS 18650 经典配置，ESP32 Lite V1.0.0 仅在客户端主动切换后生效
2026-09-13 feat: 支持按键三+按键四长按10秒安全重置蓝牙配对（保留业务配置），并在客户端增加FORGET BT按钮
2026-09-15 feat(mac): 同步 1.0.15 开发板型号切换与深度休眠时间选择功能并完成编译打包
2026-09-15 feat(mac): 同步增加 FORGET BT 遗忘蓝牙连接功能并重新编译
2026-09-22 feat: 将 ESP32 Lite V1.0.0 设为出厂默认开发板并发布 v1.0.16
    [Cover_PCB.stl, Cover_PCB_0.stl, ESP32_KeyBoard.skp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]
2026-09-22 feat(client): 集成方案B直通极速烧录引擎，完美适配 CH340 与 CP2102
    [Cover_PCB_0.stl]
2026-09-22 fix(client): 解决打包缺失 esptool targets 与 stub 数据导致的烧录中断
    [spp_client.py, vox_triple.py]
2026-10-10 feat(mac): 参考 OpenDesign 布局重构 2-Panel UI 界面并同步至 v1.0.17
2026-10-24 chore: 移除与 VoxTriple 关联，全量配置收敛至 VoxTriple_Classic
2026-11-04 fix(firmware): 修复合包分区偏移量错误，增加 flash_args 自动合包脚本
2026-11-04 fix(firmware): 精准修复 1.0.19 引脚硬件冲突，恢复黄金引脚定义并强化双设备切换抗噪防抖

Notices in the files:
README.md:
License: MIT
